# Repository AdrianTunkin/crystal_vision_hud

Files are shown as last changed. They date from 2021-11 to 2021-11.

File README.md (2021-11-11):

# CRYSTAL VISION HUD
### Head-Up Display (HUD) System for safe driving

#### Attention: This repository does not contain diagrams and drawings of projector optics. 
#### Also repository does not contain information regarding mechanical parts, including servos.

Crystal Vision is a portable Head-Up Display (HUD) system that projects an image on the windshield of your car. 
Both the driver and the passengers see it as a semi-transparent image that “levitates” over the hood of the car.

#### Copyright (C) 2015-2018, Crystal Vision Ltd.

https://user-images.githubusercontent.com/49099551/141296656-99a9382b-fc6b-408f-bb68-5c6743e9c2cb.mp4

## VISUAL CHARACTERISTICS

* Resolution: 854 x 480
* Perceived distance: 1.8-2.2 meters (depends on winshield geometry)
* Size: 17"
* Frequency: 60 Hz
* Color coverage:  ~70% sRGB
* Brightness: 1150 cd/m² (only for visible parts)
* Proprietary Remote Canvas technology

## TECHNICAL SPECIFICATIONS

* CPU: Allwinner H6 Quad-Core 64-bit Cortex-A53 @ 1.8GHz
* RAM: LPDDR3 2Gb @ 533Mhz
* ROM: 32Gb TF/MMC
* Power supply: DC 12V, 1.2A (max)
* Interfaces: IEEE 802.11 b/g/n (WiFi), Bluetooth 5.1, USB 2.0, OBDII
* Control OS: Android 9.0 Pie
* Dimensions: 83mm x 52mm x 30mm
* Weight: 115g

## TERMINOLOGY

* Projector - device for displaying projected images in windshield.
* Host phone — the phone on which the manager and client applications are installed.
* Manager - a gateway program through which client applications send graphic messages to the projector.
* Client application - an android application that, using the RemoteCanvas API, draws graphic messages on the projector. 

## DESCRIPTION

The CRYSTAL_HUD_MANAGER module is an android application that is installed on the host phone and acts as a gateway through which applications send messages to the projector.

The CRYSTAL_HUD_MANAGER function as a gateway includes:
* Controlling the concurrent access model of client applications to the projector
* Prioritize access for different applications
* Authorization of client applications.
* Work with three modes: asynchronous messages, synchronous messages, streaming. 

## WEB RESOURCES:

http://crystal-hud.tech Crystal Vision HUD information web site

https://github.com/AdrianTunkin/crystal_vision_hud - GitHub web site hosting the Hardware and Software sources

## LICENSE

### HARDWARE
The Hardware project is released under the Creative Commons Attribution-Share Alike 3.0 United States License.
You may reproduce it for both your own personal use, and for commercial use. 
You will have to provide a link to the original creator of the project http://crystal-hud.tech on any documentation or website.
You may also modify the files, but you must then release them as well under the same terms.
Credit can be attributed through a link to the creator website: http://crystal-hud.tech

### SOFTWARE
The software is released under GPL3.

### DOCUMENTATION
The documentation is released under the Creative Commons Attribution-Share Alike 3.0 United States License.

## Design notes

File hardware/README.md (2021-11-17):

# CRYSTAL VISION HUD
### Head-Up Display (HUD) System for safe driving

Crystal Vision is a portable Head-Up Display (HUD) system that projects an image on the windshield of your car. 
Both the driver and the passengers see it as a semi-transparent image that “levitates” over the hood of the car.

#### Copyright (C) 2015-2018, Crystal Vision Ltd.

Hardware directory contains hardware schematics, design sources, and revision changes designed in KiCad EDA software.



The Crystal Vision HUD electronic board is 6 layer PCB.

#### Technical specifications

* CPU: Allwinner H6 Quad-Core 64-bit Cortex-A53 @ 1.8GHz
* RAM: LPDDR3 2Gb @ 533Mhz
* ROM: 32Gb TF/MMC
* Power supply: DC 12V, 1.2A (max)
* Interfaces: IEEE 802.11 b/g/n (WiFi), Bluetooth 5.1, USB 2.0

Crystal-HUD PCB

### Hardware revision changes log:

#### Hardware revision 1.0

* initial release

#### Hardware revision 1.1

* 1. Adjusted white print of label
* 2. Added bypass near FET2
* 3. Added white print for the UART connector at the bottom of the board
* 4. Fixed white print of R106 and R116
* 5. R29 placed a bit further from C84

#### Hardware revision 2.0

* 1. Changed from eMMC 4GB 1.00mm pitch to eMMC  16GB 0.50mm pitch.
* 2. C212 and C213 were increased to 33pF and to 0402.
* 3. R66 value changed from NA(0R) to NA(22R)
* 4. RM15's package changed from RA1206_(4X0603)_4B8_22R to RA0805_(4X0402)_22R as component optimisation.
* 5. C119 and VR1 changed from PTH to SMT type in the KiCad settings. In reallity, C119 and VR1 did not change. 
* 6. PWRLED1 and CHGLED1 labels corrected in the white print.
* 7. WP_Enable1 jumper added to the SPI_Flash.
* 8. U4 changed from NA(H27UBG8T2BTR-BC(TSOP48)) to NA(MT29F64G08CBABA-WP(TSOP48)), i.e. when populated 8GB NAND instead of 4GB.

#### Hardware revision 2.1

* 1. eMMC KLMAG2GEND-B031(FBGA153)(16G) changed with new eMMC KLMAG1JETD-B041(FBGA153)(16G)

#### Hardware revision 2.2

* 1. Added R62(10k/0402) pull-down to the eMMC's data strobe line;
* 2. RM14, RA0805_(4X0402)_22R replaced by 4 resistors 22R/0402, i.e. R121-R124;
* 3. R73[NA(22R/0402)] was added to enable SPI0 software CS option to the UEXT via PH10, when the SPI_Flash is populated.
* 4. L9 was changed from 2.7nH/L0402 to NA(2.7nH/L0402), and C88 from 24pF to NA(24pF);
* 5. MIPI-DSI1 changed: MIPI-DSI1 connector's pinout completely changed for Raspberry-Pi compatability; added the resistors: R125 to R132;
* 6. In the DRC drill to drill clerance was set to 12mils and all related errors were corrected;
* 7. UEXT1 was changed from NA(HN2x5) to HN2x5;
* 8. All 3Ds were assigned;
* 9. It was added C94(NA/0402) to the eMMC's clock line just in case;
* 10. NAND and related components removed forever;
* 11. In the schematic all "/" signs were exchanged with "\";
* 12. Improvements around the placement of a number of resistors related to the PHY signals to reduce EMI emissions;
* 13. Added U4 EEPROM - AT24C16C-SSHM-T(SOIC-8_150mil) and also C39, 100nF/10V/10% to the UEXT's I2C to avoid conflict with the same EEPROM
* 14. R15[NA(22R/R0402)] added in serial to the eMMC's datastrobe signal to be able to disconnect when no HS400 mode or to add a serial filter to reduce EMI;
* 15. U2 and U3's packages improved;

#### Hardware revision 2.3

* 1. Added antenna ANT2(NA(U.FL-R-SMT-1)), R16(0R) and R17(NA/0R);
* 2. Removed FB1(FB0402/PZ1005U601-R45TF-1) and FB2(FB0402/PZ1005U601-R45TF-1) and placed R18(22R/0402) and R19(22R/0402) resistors instead.;
* 3. Adjusted the lengths of some eMMC wires;
* 4. C93 changed from 24pF to 24pF\50V/5%. C88 and C198 changed from NA/24pF to NA(24pF\50V/5%);
* 5. Changing 5.1 eMMC at 3.3V (up from 1.8V operation) for better reliability, PWR_PC1 jumper has to be set to position 1-2 for 3.3V operation.

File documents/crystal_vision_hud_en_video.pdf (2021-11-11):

# Crystal Vision

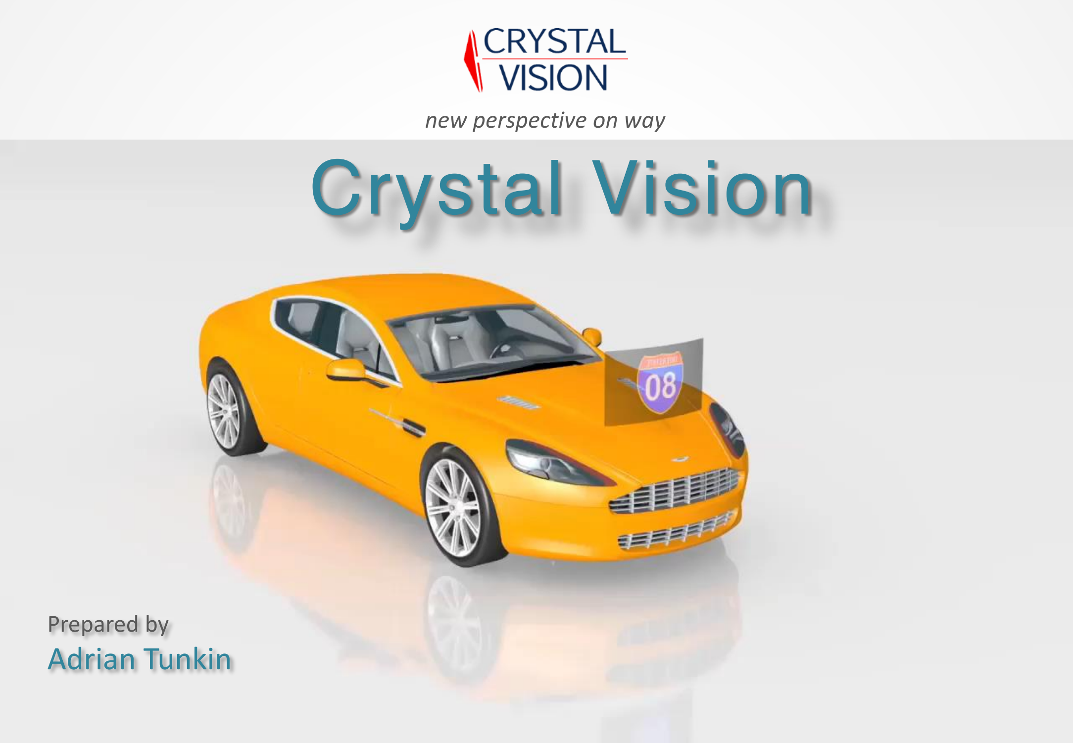
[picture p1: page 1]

new perspective on way

Prepared by

## Adrian Tunkin

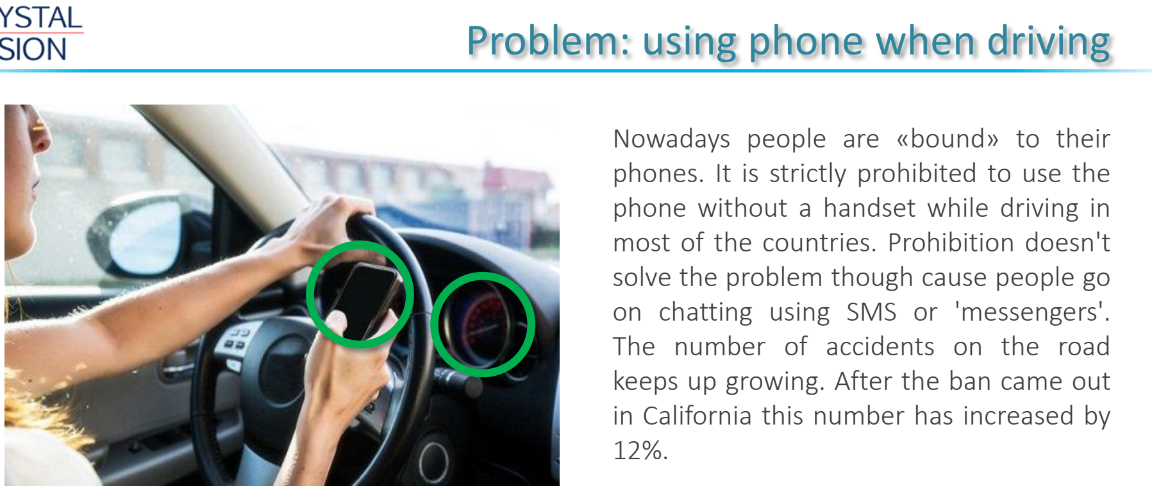
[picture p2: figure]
Problem: using phone when driving; Nowadays people are «bound» to their; on chatting using SMS or 'messengers'. The number of accidents on the road

Looking away from the road for just 2 seconds increases the risk of an accident by 9 to 24-fold

About 78% of people use the smartphone behind the wheel

Only eye refocusing takes 0.3 -0.6 sec which gives extra 50 feet to braking distance

Reflex time increases by 400% while typing SMS or checking email at the wheel

www.crystal-hud.com

phones. It is strictly prohibited to use the phone without a handset while driving in most of the countries. Prohibition doesn't solve the problem though cause people go

keeps up growing. After the ban came out in California this number has increased by

## Frightening consequences

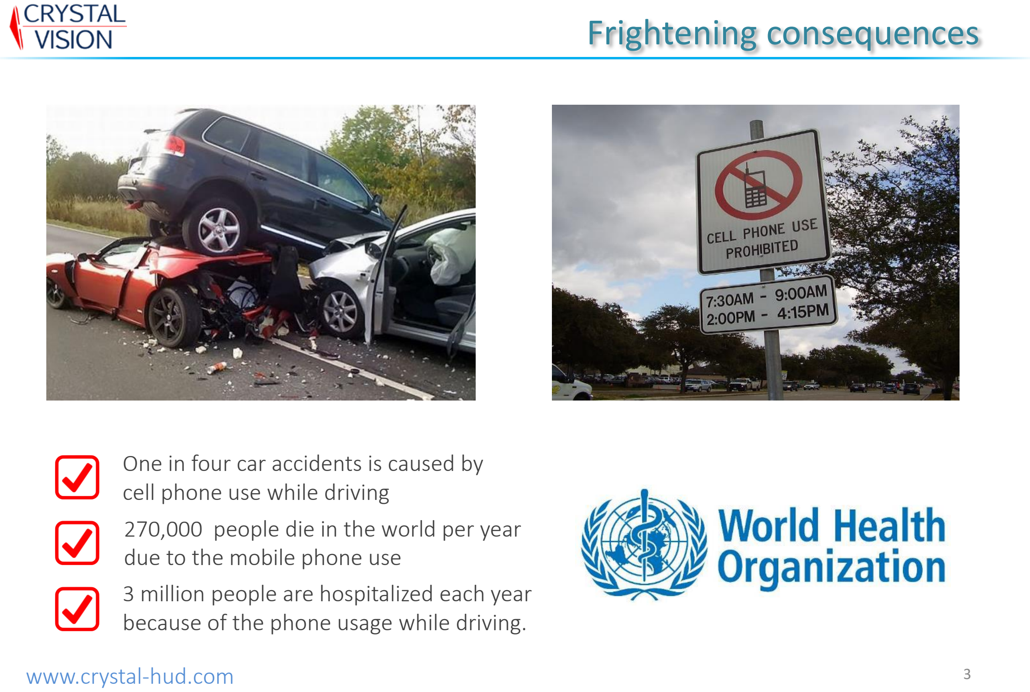
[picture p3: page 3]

270,000 people die in the world per year due to the mobile phone use
3 million people are hospitalized each year because of the phone usage while driving.

One in four car accidents is caused by cell phone use while driving

## Solution: Crystal Vision HUD

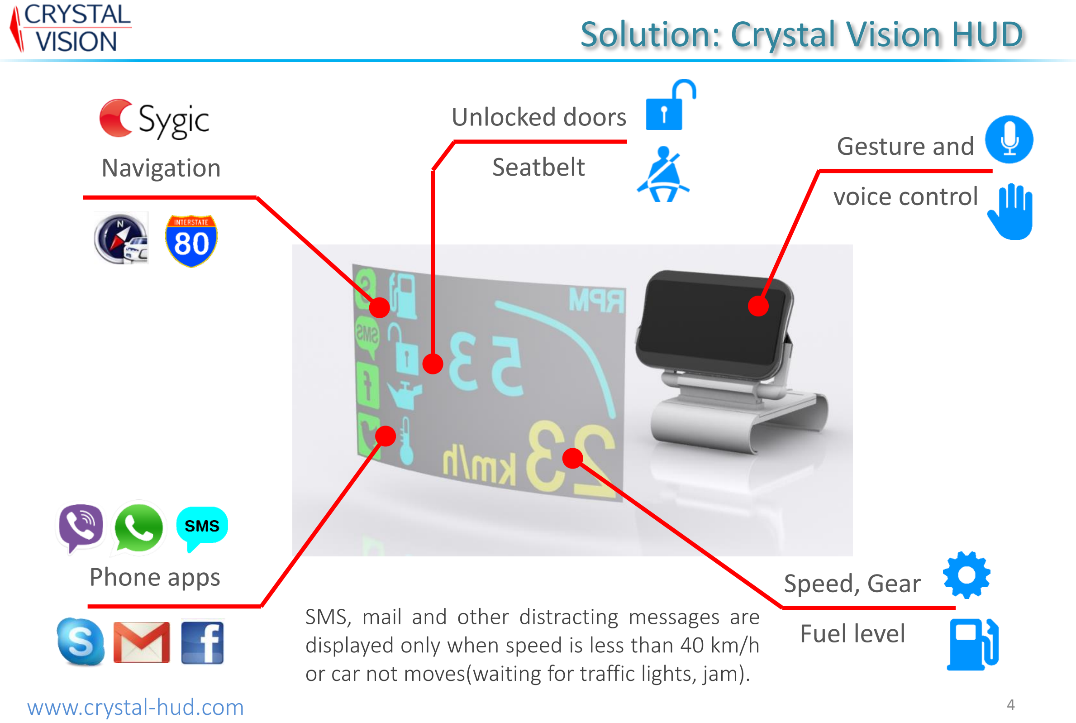
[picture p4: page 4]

Navigation

Speed, Gear

Fuel level

Unlocked doors

Seatbelt

Phone apps

Gesture and

voice control

SMS, mail and other distracting messages are displayed only when speed is less than 40 km/h or car not moves(waiting for traffic lights, jam).

Crystal Vision is a portable HUD system, that projects image on a windshield of your car. Driver and passengers see it as a semitransparent image that “levitates” above the car bumper and is not seen from outside. Projector is controlled via an app installed on the smartphone. The application aggregates data from the cloud services and smartphone applications, onboard computer and sends it in a special format to the projector. See the video. (https://youtu.be/zcKgM1mWc0Q)

Application
manager

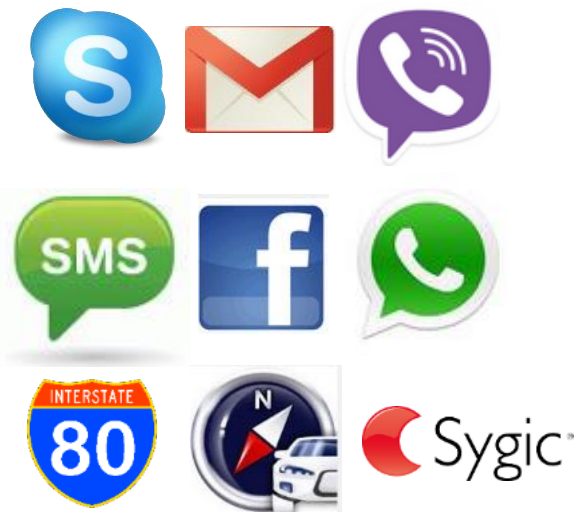
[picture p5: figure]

3d party applications
(info providers)

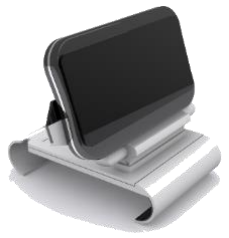
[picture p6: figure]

API

Crystal Vision HUD

## Created image examples

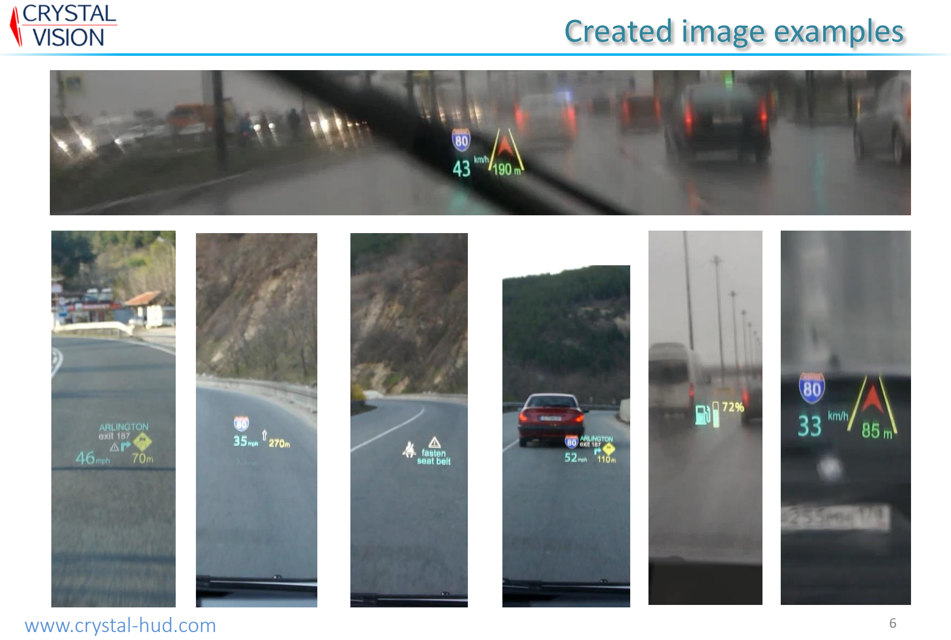
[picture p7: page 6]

www.crystal | 6 -hud.com

Currently in the World there are only a few competitors that offer embedded HUD systems. They are early bird companies that only offer pre-ordering their products.

Continental provides factory installed solutions for luxury cars segment. Audi, BMW, Mercedes: all those brands are equipped with Continental HUD systems if option is chosen when ordering car.

Crystal creates pristine image that is of the same quality as created by HUD systems in luxury cars.
Crystal HUD is portable and can be installed into any car.

Crystal vs. factory

Crystal HUD cost is 5 to 10 times less than factory HUD systems and is the same for embedded HUD systems.

Crystal HUD allows a variety of information to be displayed, which is chosen by a user. In contrast, factory HUDs display info is determined by manufacturer, typically, navigation only.

Crystal vs. portable

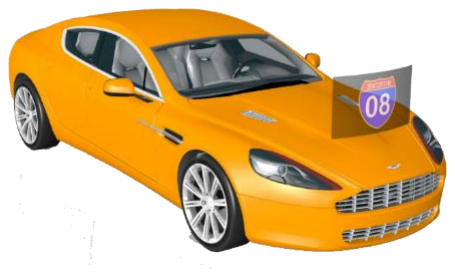
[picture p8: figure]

Since we have solved image-doubling problem, Crystal HUD doesn’t require neither reflective plates nor films, which are used in other competitive products. Image is created right on a windshield.

Image created by Crystal HUD is remote, it “levitates” over the car hood and appears to be 1,7 – 2,3 m up the driver’s eyes. This allows not to refocus the sight as the image is already in the field of vision. Driver doesn’t get distracted from the road. According to the latest research, that is crucial point for driving safety and differs Crystal HUD from other pseudo “HUD” systems.

Crystal HUD can be tuned up to show image below, on or above horizon line. Image is well seen in any conditions: day and night, sun and rain, snow and fog. Image is also seen by passengers.

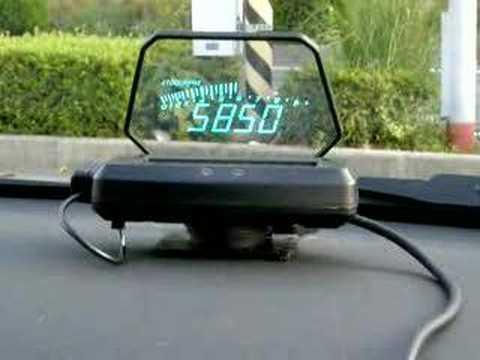
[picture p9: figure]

Competitive
portable “HUD”

## Factory HUD vs. Crystal Vision HUD

Factory HUD | Crystal Vision

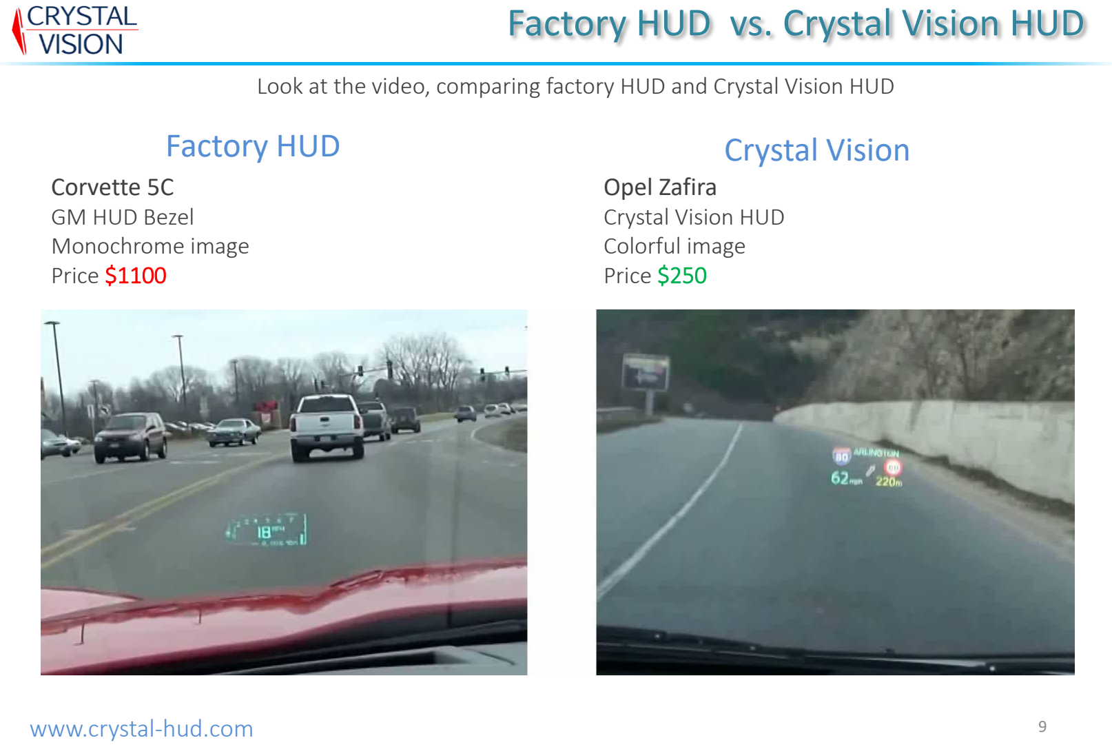
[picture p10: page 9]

Corvette 5C
GM HUD Bezel
Monochrome image
Price $1100

Opel Zafira
Crystal Vision HUD
Colorful image
Price $250

Look at the video, comparing factory HUD and Crystal Vision HUD

50%

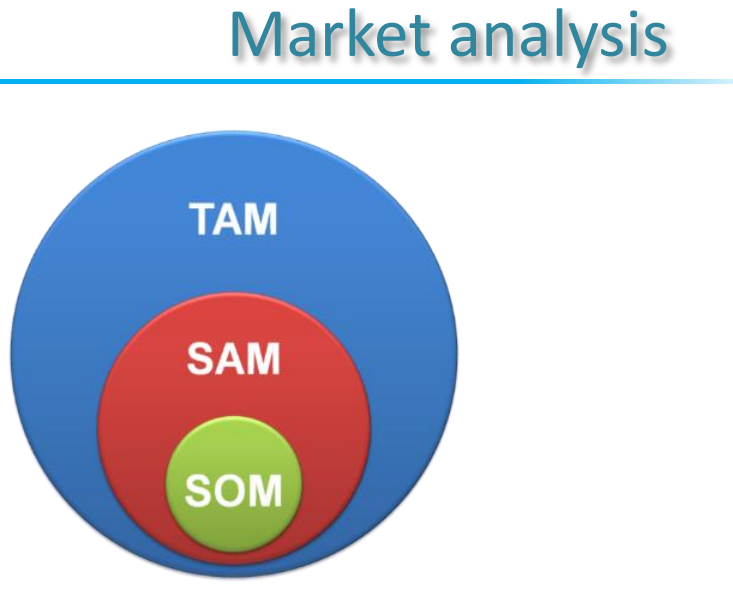
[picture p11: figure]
Market analysis

Total Available Market (TAM) = 1150 m. – all cars in the world driven every day

Serviceable Available Market (SAM) = TAM x 87% - passenger cars
x 90% - cars that support technology х 70% - use smartphone while driving = 630 million

Serviceable Obtainable Market (SOM) = Russia 40 m. passenger cars + China 117 m. passenger cars +
USA 220 m. passenger cars +
Europe 250 m. passenger cars
= 627 х 90% х 70% = 395 million | 1150

630

395

0 | 500 | 1000 | 1500

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
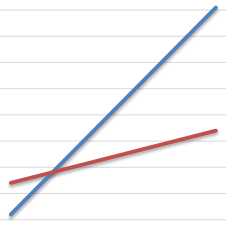
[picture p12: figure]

2012 | 2020

Growth of number of cars with HUD option, millions

0

1000

2000

3000

4000

5000

6000

7000

8000

9000

2014 | 2017 | 2020
Fast growing market,
millions of USD

According to a new market research report, the global head-up display market is estimated to reach USD 9.02 Billion by 2020, at a CAGR of 26.23% between 2015 and 2020. The market for the automotive application is expected to grow at a CAGR of 29.28% during the forecast period. This growth is driven by the increasing demand for mid-segment and sport cars globally. (source: MarketsandMarkets) (http://www.marketsandmarkets.com/Market-Reports/head-up-display-hud-market-684.html)

## How do we make money

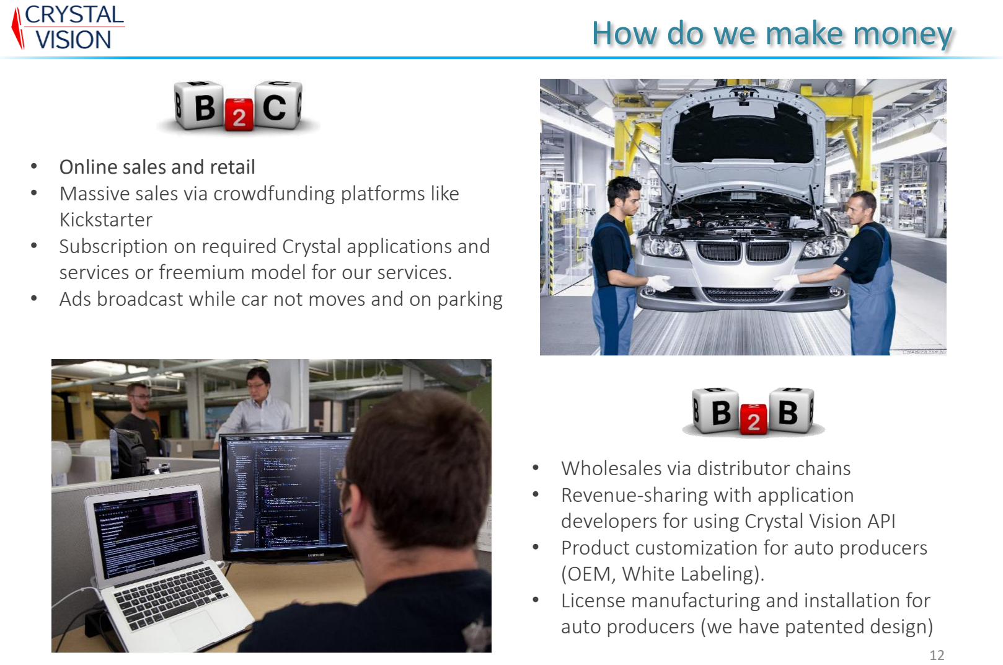
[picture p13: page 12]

- Online sales and retail
- Massive sales via crowdfunding platforms like Kickstarter
- Subscription on required Crystal applications and services or freemium model for our services.
- Ads broadcast while car not moves and on parking
- Wholesales via distributor chains
- Revenue-sharing with application developers for using Crystal Vision API
- Product customization for auto producers (OEM, White Labeling).
- License manufacturing and installation for auto producers (we have patented design)

50%

Who is interested in the product:
- Our audience - car owners.
- Car producers.

How to promote the product:

- Actually, distributors from all over the world already find us and offer partnership, distribution and promotion in their countries.
- Sales web-page http://crystal-hud.com.
- Attractive car stickers and shields in the set with the device.
- The device advertises itself attracting drivers and passengers’ attention with its outer look (from mouth to mouth marketing or “the rumour mill”).
- Equipment of foreign car rent services chains (Top Rent Car, Herz, etc.) or test-drive cars will let many people get to know the product.
- Commercials on web-sites devoted to cars (auto.ru, autoblog.com, auto.de).
- Gadgets overview web-sites (digitaltrends.com, cnet.com, engadget.com).
- Car magazines, brochures, TV-shows and video casts (“Top gear”, “Big test-drive”), social network communities, messages in blogs.

50%

- Factory HUD system | $1100 - $3000
- Pioneer HUD system NavGate | $930
- NAVDY pre-order | $299 ($499)
- Crystal Vision HUD | $250
0 | 1000 | 2000 | 3000 | 4000

Crystal Vision

Navdy

Embedded HUDs

Pioneer NavGate

Factory HUDs

max min

50%

Crystal Vision projector
1. Patent pending (Russian) 100%
2. Patent pending (international) 35%
3. Trademark registration | 70%
4. Minimum Functional Prototype (MFP) 100%
5. Complete Functional prototype (CFP) 92% optic elements 100%
electronics (PCB) 85%
enclosure and mount 90%
6. Design-For-Manufacture(DFM) 59%
optic elements | 100%
prototype elements | 90%
molds | 40%
certification 5%

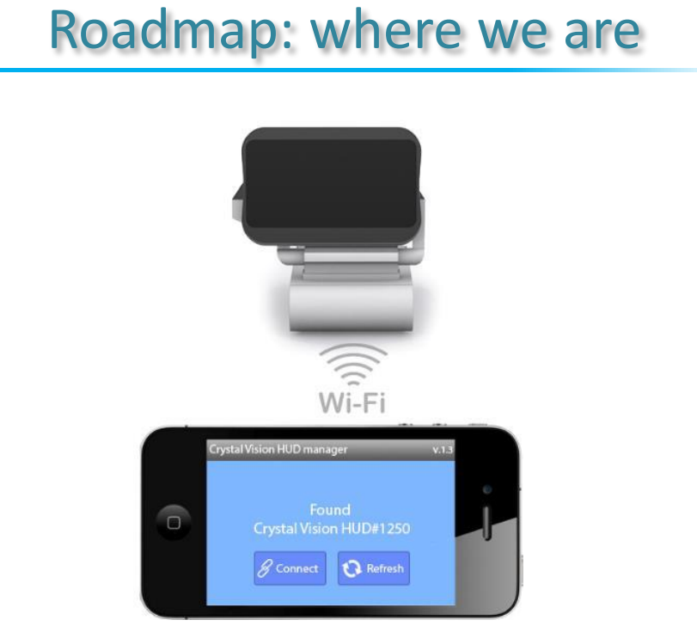
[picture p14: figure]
Roadmap: where we are

7. Suppliers of electronic components, elements and materials 100 %
8. Potential resources for manufacture, assembly, packaging 100 %
9. Packaging 0%
10. First factory run (FFR) 0%
11. Retail 0%

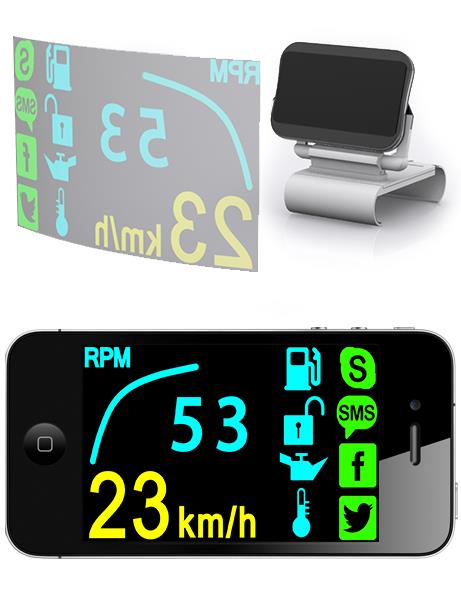
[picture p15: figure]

50%

Software development
1. Crystal Vision Application Manager
for Android 85%
for iOS 10%
2. Remote animations engine “Remote Canvas” for Android 95%
for iOS 10%

Common
1. Kickstarter campaign 70%
2. Distribution channels
USA | 40%
China | 0%
Finland 50%
Germany 10%
Thailand 70%
Bulgaria 70%
3. Marketing 2%

50%

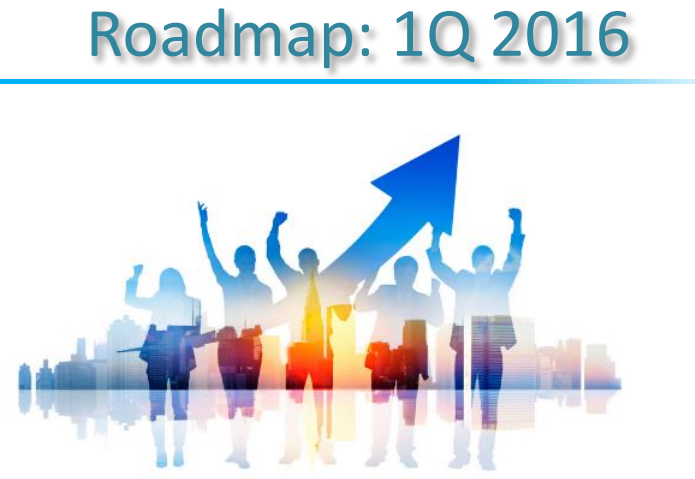
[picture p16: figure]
Roadmap: 1Q 2016

Estimated progress status at the end of 2015 - 1Q 2016

Crystal Vision projector
1. Patent pending (Russian) 100%
2. Patent pending (international) 80%
3. Trademark registration | 100%
4. Minimum Functional Prototype (MFP) 100%
5. Complete Functional prototype (CFP) 100%
6. Design-For-Manufacture (DFM) 80 - 100%
7. Suppliers of electronic components, elements and materials 100%
8. Potential resources for manufacture, assembly, packaging 100%
9. Packaging 100%
10. First factory run (FFR) 60 - 100%
11. Retail 60 - 90%

Software development
1. Crystal Vision application manager 100%
2. Remote animations engine “Remote Canvas” 100%

Common
1. Kickstarter campaign 100%
2. Distribution channels 90%
3. Marketing | 60-100%

50%

- Fixed production costs $65K
- Industrial design finalization $21K hardware finalization $11K software finalization $10K
- Assembly $32K
- Packaging $6K
- Engineering Validation Test(EVT) $2K
- Certification | $2K
- Design Verification Test(DVT) | $2K
- Delivery $12 per unit
- Variable costs $16 per unit
- Business trips 6 months | S10K
- Outsource and custom works | $5K
- International Patent finalization $20K
- First 5K batch (KickStarter campaign, distributor channels)
- Incomes - $1,250,000(5K x $250)
- Fixed costs $65 per unit
- Profit per unit $157
($250 - $65 -$12 - $16)
- Profit for batch $785,000
(5K x $157)
- Second and another batches profit per unit $170
- Distribution channels and Wholesale (FOB price $180) profit per unit $95 ($180 - $65 - $4 Delivery - $16)

## Profit 2016

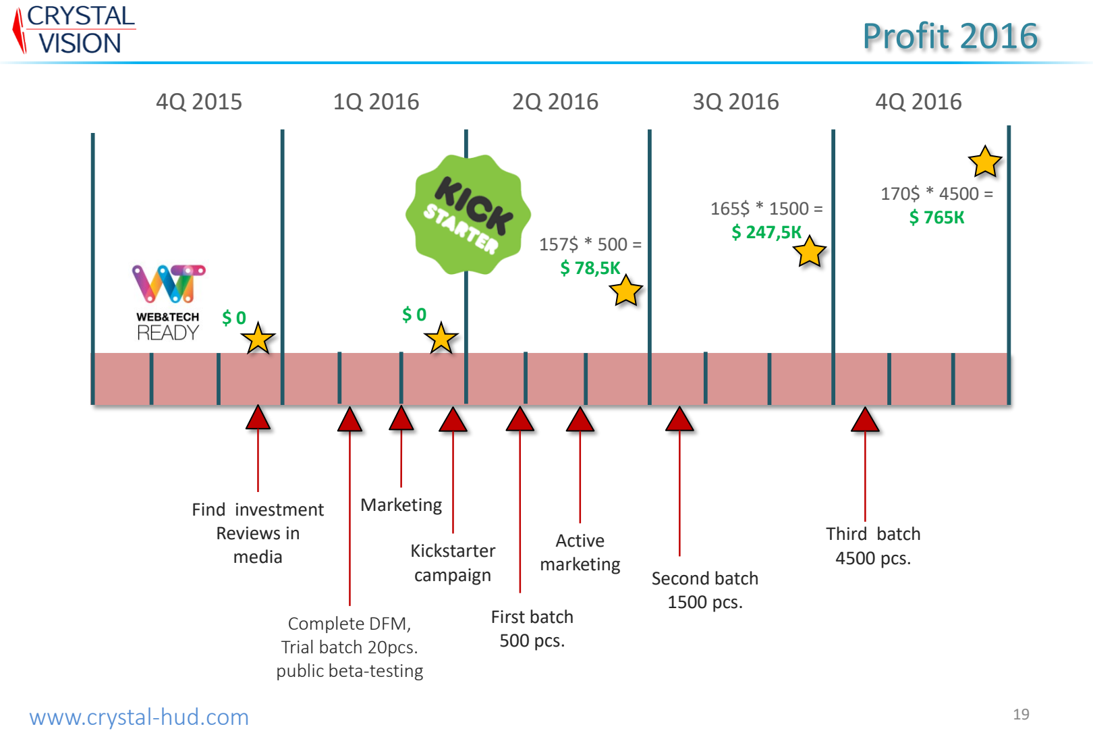
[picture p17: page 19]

4Q 2015 | 1Q 2016 | 2Q 2016 | 3Q 2016

Complete DFM,
Trial batch 20pcs.
public beta-testing

Kickstarter
campaign

First batch
500 pcs.

Active
marketing

157$ * 500 =
$ 78,5K
$ 0 | $ 0

165$ * 1500 =
$ 247,5К

Second batch
1500 pcs.

170$ * 4500 =
$ 765К

4Q 2016

Find investment
Reviews in
media

Third batch
4500 pcs.

Marketing

# | Risk | Description | Threat | Remediation

1 | Economic | Foreign exchange volatility influences the purchasing ability in different countries and price setting of the product. | High | Price division according to the country. We made a survey in different countries what price the customers are ready to pay for it.
2 | Production | Nonfulfillment of baseline work, failure to meet the deadline. | Moderate | We already have partners with two-time stock volumes. We are setting up new contacts with partners in different countries for product sales.
3 | Legal | Prohibition on Crystal HUD implemented systems usage in certain countries. | Low | Crystal HUD doesn’t use any cover-up on windshield, no reflection glass which can disturb the driver. Switch to other markets.
4 | Low demand | Low demand | Moderate, Low | Percent order in relation to the overall number of clicks on the site, 19%. Presentation, survey in the US, 65%. Presentation, survey in Germany, 71%.
5 | Strategic | Patents infringement, manufacturing of products functionally close to it. | High | Intellectual property rights, protection of interests in court.
6 | 50% Compliance | Ban of Application Manager on AppStore and Google Play Market. | Low | Compliance with the rules and guidelines for application development.
7 | Legal, Regulatory | Ecological norms and rules violation, problems of standardizing and licenses. | Low | We don’t use any toxic, poisoning or contaminating substances. We use mercury-free and lead-free components and soldering, RoHS compliant.

Until recently we didn’t participate in any events,

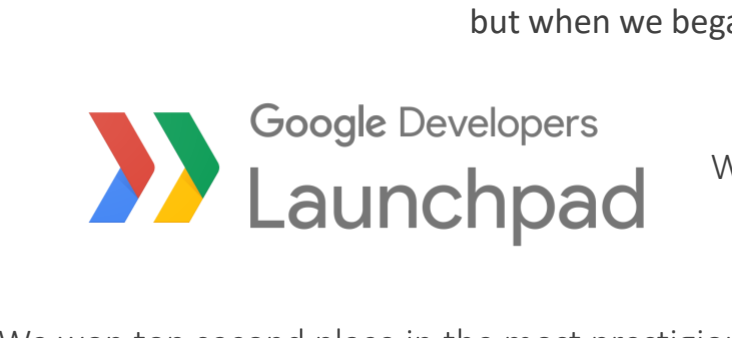
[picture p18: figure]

but when we began we won several prizes:

We are the member of Google Launchpad program.

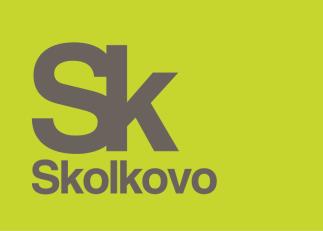
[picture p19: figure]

We’ve patented technology in RosPatent. And now still pending for technology enhancement patent.

We won top second place in the most prestigious Russian competition. There were 712 competing projects from 14 countries.

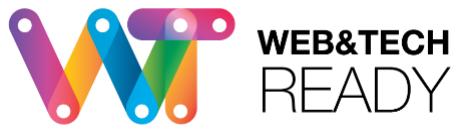
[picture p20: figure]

We won high technology acceleration program in Skolkovo Innovation Center.

## Testimonials

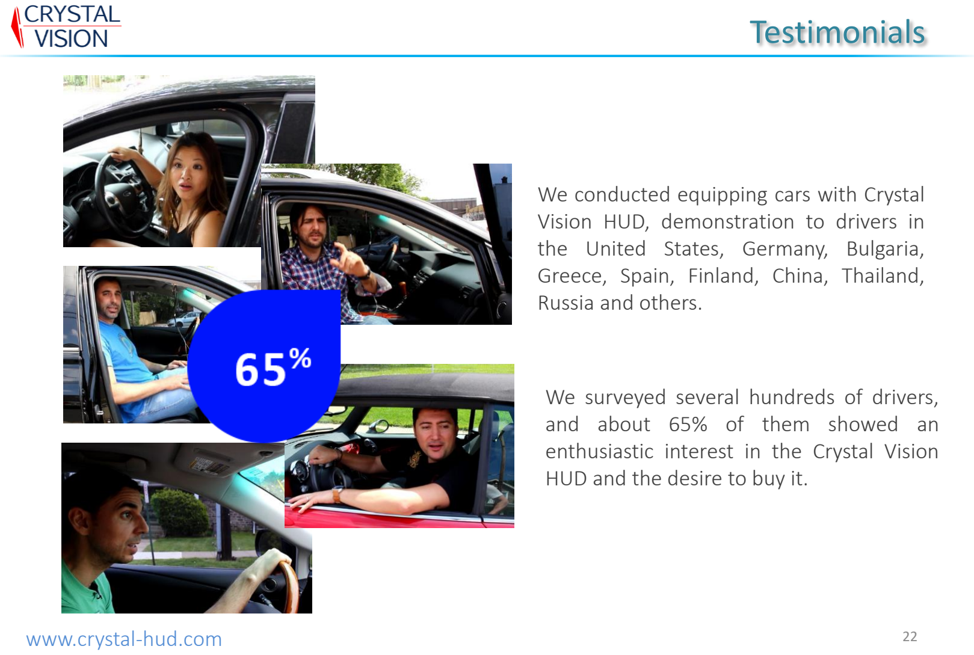
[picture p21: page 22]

We conducted equipping cars with Crystal Vision HUD, demonstration to drivers in the United States, Germany, Bulgaria, Greece, Spain, Finland, China, Thailand, Russia and others.

We surveyed several hundreds of drivers, and about 65% of them showed an enthusiastic interest in the Crystal Vision HUD and the desire to buy it.

We spent about 3 years for technology R&D, and now have finished it. Product is 75-80% ready and we will start production soon.
We need money, for:
- Finalizing industrial prototype
- Preparation for mass production
- First batch production
- Marketing
- Preparing for Kickstarter campaign (commercial and reviews in media)
- Outsourced works (design, software)
- Patenting, certification and other legal affairs

We have of about 220 preorders now. Genuine interest to our product, distribution offers, crowdfunding success of related projects (Navdy, (http://www.entrepreneur.com/article/245093) HUDWAY, (https://www.kickstarter.com/projects/361842686/hudway-glass-keeps-your-eyes-on-the-road-while-dri) Expolride) (https://www.indiegogo.com/projects/exploride-turn-your-car-into-a-smart-car#/) and our competitive advantages let us assume great success.

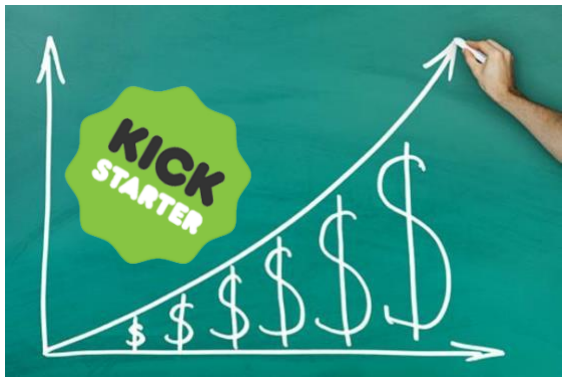
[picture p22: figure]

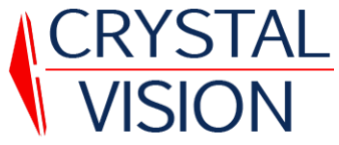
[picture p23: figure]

Let’s turn every car into a safe spaceship, and make business together

Any questions :
phone: +7(903)095-01-47
еmail: adrian@crystal-hud.com web: http://crystal-hud.com

Analytics, statistics, development prospects

- http://www.marketsandmarkets.com/Market-Reports/head-up-display-hud-market-684.html (http://www.marketsandmarkets.com/Market-Reports/head-up-display-hud-market-684.html)
- http://press.ihs.com/press-release/design-supply-chain/automotive-head-display-market-goes-high-gear (http://auto.cnews.ru/news/byid/534108)
- http://www.acea.be
- https://en.wikipedia.org/wiki/Motor_vehicle
- http://chartsbin.com/view/1114
- https://en.wikipedia.org/wiki/List_of_countries_by_vehicles_per_capita
- http://www.who.int/en/ (http://auto.cnews.ru/news/byid/534108)

HUD products
- http://www.youtube.com/watch?v=-8SP1OSIpaM (http://auto.cnews.ru/news/byid/534108)
- http://www.edmunds.com/mazda/mazda3/2014/long-term-road-test/2014-mazda-mazda3-heads-up-display.html (http://www.edmunds.com/mazda/mazda3/2014/long-term-road-test/2014-mazda-mazda3-heads-up-display.html)
- http://www.pioneer.eu/eur/products/archive/SPX-HUD01/page.html
- http://www.youtube.com/watch?v=Qg8dq9FlX78

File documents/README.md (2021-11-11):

# CRYSTAL VISION HUD
### Head-Up Display (HUD) System for safe driving

Crystal Vision is a portable Head-Up Display (HUD) system that projects an image on the windshield of your car. 
Both the driver and the passengers see it as a semi-transparent image that “levitates” over the hood of the car.

#### Copyright (C) 2015-2018, Crystal Vision Ltd.

Documents directory contains:

* English presentation
* Visio file with hierarchy of application classes
* Files, concerned the patent

The patent itself is written in Russian (not translated).

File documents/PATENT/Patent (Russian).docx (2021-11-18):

МПК G02B 27/01

Название изобретения

Метод формирования мнимого изображения для системы проецирования информации на лобовое стекло HUD(Head Up Display).

Область техники, к которой относится изобретение

Изобретение относится к системам проецирования информации на лобовое стекло, в частности на лобовое стекло автомобиля. Эта система позволяет создавать мнимое изображение, которое висит над капотом или бампером автомобиля, и позволяет водителю управлять транспортным средством, не отвлекаясь от дороги. Показания скорости, оборотов, навигационные данные или другие данные сами попадают в поле зрения и не требуют перефокусировки зрения для чтения информации. Такие системы называются системами HUD(от англ. Head Up Display). Сейчас такие системы так же называются расширителями дополненной реальности – от англ. AR Devices(Augmented Reality Devices).

Далее в этом документе системы проецирования информации на лобовое стекло будут называться системами HUD.

Уровень техники

Известны штатные (заводские) системы HUD и встраиваемые системы HUD.

Штатные системы HUD - это сложные оптические системы, которые расчитываются под конкретную марку автомобиля и предполагают заводскую установку и настройку при сборке автомобиля. Как и любая оптическая система, система HUD занимает некоторый объем, поэтому в пространстве передней панели должно быть место для установки системы HUD. Так же в передней панели должно быть окно для прохождения светового потока от изображения. Кроме того ключевую роль в таких системах играет лобовое стекло, которое должно создавать четкое изображение без раздвоения. Лобовое стекло является самым дорогостоящим оптическим элементом систем HUD.

Установка штатной системы HUD невозможна после выпуска и продажи автомобиля.

Большинство патентов на системы HUD - это патенты на штатные (заводские) системы, устанавливаемые при сборке автомобиля.

Недостатками штатных систем HUD являются:

1. Очень высокая стоимость систем, технологическая сложность изготовления лобовых стекол.
2. Система должна быть запрошена при заказе автомобиля. Дальнейшая установка системы HUD невозможна или очень дорогостоящая.
3. Изображение видно только водителю и не видно пассажирам, а есть необходимость выводить не только автомобильную информацию для водителя, но и общеполезную информацию для всех пассажиров.

Существуют также встраиваемые системы HUD. Эти системы разработаны для установки в автомобили, у которых нет штатной системы HUD.

Примеры встраиваемых систем HUD:

- встраиваемая система HUD производства Garmin [1];
- встраиваемая система HUD производства Defi [2];

Эти системы представляют собой законченные устройства в корпусе. Устройство устанавливается на переднюю панель автомобиля и фиксируется двухсторонней липкой лентой. В корпусе есть микропроцессор и зашита программа, которые обрабатывают данные автомобиля, или мобильного телефона поступающие по интерфейсу Bluetooth.

Микропроцессор создает изображение на индикационном элементе устройства. Это изображение отражается от лобового стекла автомобиля, или от специального тонкого поликарбонатного стекла, крепящегося к самому устройству.

Недостатками этих встраиваемых систем HUD являются:

1. Для корректной работы этих систем требуется специальное отражающее стекло, которое идет в комплекте с устройством и крепится к самому устройству, либо специальная отражающая или затемняющая пленка, которая клеится к лобовому стеклу. Посторонние предметы на лобовом стекле (пленка) или отражающее стекло крайне нежелательны, так как отвлекают водителя от вождения и загораживают вид водителю. К тому же они нарушают эргономичность всей системы HUD.
2. Недостатком этих систем является то, что они создают мнимое изображение на уровне лобового стекла, а не над бампером как в заводских системах HUD.
3. Недостатком является то, изображение видно только водителю и не видно пассажирам, а есть необходимость выводить не только автомобильную информацию для водителя, но и общеполезную информацию для всех пассажиров.
4. Недостатком является то, что у приведенных выше встраиваемых систем HUD изображение не графическое. Отображаются только предопределенные символы и ограниченный набор фигур.

Известна также встраиваемая система HUD производства фирмы Pioneer [3].

Система производится в корпусе, который крепится ремешками к солнцезащитному козырьку автомобиля. В корпусе есть микропроцессор и зашита программа, которые обрабатывают данные бортового компьютера автомобиля, или данные с мобильного телефона, поступающие по интерфейсу Bluetooth. Микропроцессор и программное обеспечение формируют изображение на дисплее устройства. Дисплей находится со стороны головы водителя и формирует световой поток изображения в сторону лобового стекла. Изображение, формируемое дисплеем, отражается от изогнутой поликарбонатной пластинки на стороне устройства, находящейся со стороны лобового стекла. Водителем это изображение воспринимается как удаленное увеличенное изображение.

Недостатками данной системы являются:

1. Информация проецируется не на лобовое стекло, а на стеклянную панель перед глазами водителя. Это вызывает неудобство водителя.
2. Недостатком является то, что данная система также создает недостаточно удаленное мнимое изображение.
3. Недостатком является то, изображение видно только водителю и не видно пассажирам, а есть необходимость выводить не только автомобильную информацию для водителя, но и общеполезную информацию для всех пассажиров.

Наиболее близким аналогом данного изобретения является система HUD описанная в патентной заявке США US7990620 B2 от 02.08.2011 см. Приложение 1, фиг.15. Эта система использует источник излучения (лазерный луч) 102, который формирует изображение на рассеивающем элементе 104 (белый лист, экран и т.д.). Реальное изображение, формируемое рассеивающим элементом 104 установленным на передней панели 108, отражается от лобового стекла 106 и попадает в глаз водителя.

Главным недостатком данной системы HUD является то, что независимо от расположения источника света (лазерного луча)102, реальное изображение формируется не на источнике излучения, а на рассеивающем элементе 104, который располагается на передней панели автомобиля 108. Это означает, что удаленность Dv мнимого изображения 114 равна расстоянию от рассеивающего элемента 104, лежащего на передней панели 108, до места отражения на лобовом стекле 106, то есть Dv = Dp. Данное расстояние в среднем равно 170 миллиметрам.

Кроме того, поскольку удаленность мнимого изображения мала, изображение сильно двоится. Поэтому использование этой системы возможно только со специальным лобовым стеклом (аналогичным штатным системам HUD) или с использованием дополнительных отражающих стекол или отражающих пленок на лобовом стекле (аналогичным встраиваемым системам HUD от Garmin или Defi).

Раскрытие изобретения

Задача, на решение которой направлено заявляемое изобретение, состоит в том, чтобы создать систему HUD, в значительной мере свободную от перечисленных выше недостатков штатных и встраиваемых систем HUD, а также аналогов. Так же, поскольку информация может быть не только сугубо автомобильной, предназначенной для водителя, но и общеполезной для всех пассажиров, при разработке сделан акцент на возможность формирования изображения, видимого всем пассажирам. Заявляемая встраиваемая система HUD включает в себя:

- микропроцессорное устройство 3, получающее информацию из автомобиля или мобильного телефона, обрабатывающее ее и отображающее на дисплее 12;

- универсальное крепление устройства 3а, позволяющее крепить устройство 3 к солнцезащитному козырьку 1 или центральному зеркалу заднего вида 2. Крепление позволяет настраивать угол устройства так, чтобы световой поток дисплея 12 был направлен на отражающий элемент 4;

- один или несколько отражающих элементов 4, представляющих собой оптическое или промышленное зеркало. Несколько отражающих элементов используются, когда необходимо формировать изображения для нескольких пассажиров. По одному отражающему элементу на каждого пассажира;

Техническим результатом изобретения является реализация усовершенствованного метода создания мнимого изображения встраиваемой системы HUD. Предложенный метод построения изображения не использует сложную оптику: ни линзы, ни вогнутые, ни выпуклые зеркала, ни дорогостоящие лобовое стекло или другие элементы.

Основными достоинствами данного метода являются:

- Метод позволяет встраивать систему HUD в любой автомобиль. И в тот, в котором есть штатная система HUD и в тот, в котором нет штатной системы HUD.
- Метод позволяет создавать мнимое изображение, удаленность которого сравнима с удаленностью изображения штатных систем HUD, а иногда ее и превосходит.
- Метод позволяет создавать мнимое изображение, удаленность которого превосходит удаленность всех существующих (описанных выше) встраиваемых систем HUD.
- Метод формирует мнимое изображение, четкость которого сравнима со штатными системами HUD
- В отличие от других встраиваемых систем HUD, метод позволяет отказаться от использования специальных отражающих пленок и других элементов.
- Метод позволяет создавать изображения, которые видны не только водителю, но и пассажирам.

Все это достигается за счет особого расположения источника реального изображения, а так же метода формирования графического изображения.

Источником изображения может быть светодиодная матрица, дисплей или любой другой источник реального изображения. Источник реального изображения крепится на центральное (внутреннее) зеркало заднего вида, находящееся на лобовом стекле, с обратной его стороны. Так же возможно крепление за центральное зеркало заднего вида на лобовое стекло. Вторым, более предпочтительным вариантом является крепление источника реального изображения к солнцезащитным козырькам автомобиля.

Описание чертежей

На фиг.1 представлен способ крепления источника реального изображения на солнцезащитный козырек, ход луча от источника, а также формирование мнимого изображения.

На фиг.2 представлен способ крепления источника реального изображения на центральное зеркало заднего вида, ход луча от источника, а также формирование мнимого изображения.

На фиг.3 изображен путь распространения света в толще лобового стекла в общем случае

На фиг.4 изображен путь распространения света в толще лобового стекла в случае, когда расстояние от реального изображения до лобового стекла меньше, чем расстояние от лобового стекла до глаза.

На фиг.5 изображен путь распространения света в толще лобового стекла в случае, когда расстояние от реального изображения до лобового стекла больше, чем расстояние от лобового стекла до глаза.

На фиг.6 представлены сравнительные графики процентной доли отражения горизонтально-поляризованного света(s-polarization) и вертикально-поляризованного света (p-polarization) в зависимости от угла падения луча.

На фиг.7 показан эффект полной горизонтальной поляризации (s-polarization) отраженного луча, при его падении на поверхность лобового стекла под углом Брюстера.

На фиг.8 изображено в профиль устройство 3. Также на рисунке в профиль показан дисплей 12 с горизонтально-поляризующей пленкой, или пленкой, вращающей плоскость поляризации(retarder film), а также формируемые горизонтально-поляризованные лучи света 13.

На фиг.9 представлена конструкция отражающего элемента с горизонтально поляризованной пленкой.

На фиг.10 представлена возможная конструкция изготовления передней панели со встроенным отражающим элементом для системы HUD при промышленном встраивании системы автомобили.

На фиг.11 представлена возможная конструкция изготовления передней панели со встроенным отражающим элементом для системы HUD и необходимыми плоскостями вращения зеркала при промышленном встраивании системы в автомобили.

На фиг.12 показано раздвоение обычного символа со скруглениями.

На фиг.13 показан пример цифр с прямоугольными элементами.

На фиг.14 представлен пример раздвоения цифр с прямоугольными элементами.

На фиг.15 (в Приложении 1) представлен рисунок, взятый из патента US7990620 B2 от 02.08.2011. На рисунке представлен принцип формирования мнимого изображения, заявленного в патентной заявке США US7990620 B2 от 02.08.2011.

Осуществление изобретения

В системе HUD используются устройство 3, заключенное в небольшой корпус, сравнимый по размерам с современными небольшими мобильными телефонами. Устройство 3 при помощи подвижного крепления 3а, позволяющего менять угол устройства 3, крепится к солнцезащитному козырьку 1 или на центральное зеркало заднего вида 2. Внутри корпуса устройства 3 установлена электронная плата с микропроцессором и зашита программа. Устройство 3 подключается к автомобилю и/или телефону через интерфейс Bluetooth и запрашивает данные с автомобиля и телефона. Микропроцессор и программа обрабатывают данные, и выводят их на индикационный элемент, который представляет собой дисплей. Дисплей формирует реальное перевернутое изображение. Устройство 3 устанавливается так, чтобы световой поток изображения от дисплея был направлен на отражающий элемент 4 (см. фиг.1 и фиг.2) . Отражающий элемент 4, в качестве которого может выступать оптическое или промышленное тонкое зеркало, отражает изображение, формируемое устройством 3, на область лобового стекла 5.

Далее световой поток изображения снова отражается от лобового стекла в области 5 и попадает в глаз водителя 7.

Формула изобретения

В заявленном методе формирования мнимого изображения для системы HUD, расстояния L1 и L2 (см. фиг.1 и фиг.2) складываются, и удаленность S мнимого изображения 6 равна сумме этих расстояний, т.е. S = L1 + L2.

Оценка степени раздвоения мнимого изображения в заявленном методе формирования мнимого изображения и сравнение его с другими системами:

1. Анализ расстояния S для разных марок автомобилей показывает, что среднее значение S для случая крепления источника изображения на солнцезащитный козырек 1 (см. фиг.1) составляет 1220 мм. То есть S = 1220 мм.
2. Анализ расстояния от области отражения лобового стекла 5 до глаза водителя 7 для разных марок автомобилей в среднем составляет 720 мм.

То есть считаем, что C1B = 720 мм.

3. На фиг.3 изображен общий случай распространения луча в толще лобового стекла 16. Из фиг.3 видно: поскольку из геометрической оптики известно, что угол падения равен углу отражения, следовательно, ∠ CBF = η = ∠ C1BF1 = η1.

Аналогично угол ∠ ADE = β = ∠ A1DE1 = β1, из этого следует, что α = α1.

Из равенства углов α и α1 следует равенство прилежащих к ним углов θ и θ1.

Углы δ = 180 – η – θ, δ1 = 180 – η1 – β1 также равны, то есть δ = δ1.

4. Итак, у треугольников ∆CBA и ∆C1BA1 соответственно равны углы:

θ = θ1, η = η1, δ = δ1. Это означает подобие треугольников ∆CBA и ∆C1BA1, то есть ∆CBA ~ ∆C1BA1.

5. Расчет величины AA1: у современных лобовых стекол средняя толщина 5 мм, индекс преломления n = 1.51. Угол падения луча с отражающего элемента 4 на лобовое стекло в области 5 приблизительно равняется ∠(90-η)= 49° . Применяя закон Снеллиуса, получаем:

n=1.51=(sin⁡(90-η))/(sin⁡(90-β))

то есть sin(90-β)= 0.5, а угол ∠(90-η)=30° .

Отсюда получаем AA1 =2*tan(30°)*5мм=5.77 мм

6. Из подобия треугольников ∆CBA и ∆C1BA1 следует равенство отношения их сторон, то есть:

(C1B)/(CB)=(A1B)/(AB)

7. Рассчитаем A1B для системы HUD, предложенной в заявляемом изобретении:

A1B = (C1B * A1A)/(C1B+CB)= (720 * 5.77)/(720+1220) = 2.1 мм

Применяя закон синусов к треугольнику ∆C1BA1, получаем:

sin(δ1) = (A1B * sin⁡(η1))/(C1B)=(2,1 * sin⁡(41°))/720 = 0,0019

δ1 = 0,108 °= 6'29"

8. Проведем аналогичные расчеты A1B для изобретения, предложенного в аналогичной патентной заявке США US7990620 B2 от 02.08.2011:

A1B = (C1B * A1A)/(C1B+CB)= (720 * 5.77)/(720+15) = 5.65 мм

Применяя закон синусов к треугольнику ∆C1BA1, получаем:

sin(δ1) = (A1B * sin⁡(η1))/(C1B)=(5,65 * sin⁡(41°))/720 = 0,0051

δ1 = 0,29 ° = 17'24"

Сравним результаты пунктов 8 и 9:

Раздвоение изображения созданного методом приведенном в заявляемом изобретении составляет 2.1 мм (см. пункт 8), при этом угол расхождения двоящихся элементов δ1 составляет 6'29".

Раздвоение изображения в аналогичной патентной заявке США US7990620 B2 от 02.08.2011 составляет 5.65мм, при этом угол расхождения двоящихся элементов δ1 составляет 17'24", что в 2.7 раза больше, чем в методе заявляемого изобретения.

Поскольку удаленность реального изображения от лобового стекла для встраиваемых систем Garmin (см. [1]) и Defi (см. [2]) приблизительно равна удаленности реального изображения в методе, заявленном в патентной заявке США US7990620 B2 от 02.08.2011, расчет степени раздвоения дали бы результат аналогичный п.9, то есть раздвоение на уровне 5.65мм. Именно поэтому в системах Garmin (см. [1]) и Defi (см. [2]) необходимо использовать специальные отражающие элементы (стекла и пленки) для создания нормального читабельного изображения.

Фиг.4 соответствует выше упомянутым встраиваемым системам HUD Garmin, Defi.

Фиг.5 соответствует текущему заявляемому изобретению метода создания мнимого изображения для системы HUD.

Исследования показали, что отражения от лобового стекла в области 5 (см. фиг.1 и фиг.2) происходят под углами близкими к углу Брюстера. При этом эффективное отражение от лобового стекла при этих углах имеет горизонтально-поляризованный (s-polarized) свет.
На фиг.6 показан график процентной доли отражения горизонтально-поляризованного и вертикально-поляризованного лучей. Из графика видно, что вертикально-поляризованный (p-polarized) имеет очень низкий процент отражения на углах, близких к углу Брюстера.
А при угле Брюстера падающий световой поток 9 при отражении становится полностью горизонтально-поляризованным 10 (см. фиг.7). Это означает, что источник изображения должен быть горизонтально поляризованным, поскольку вертикально-поляризованная составляющая не участвует в формировании итогового изображения на лобовом стекле, но при этом снижается на 55% уровень засветки передней панели и приборной панели, что очень важно для работы системы в ночное время.

На фиг.8 изображено устройство 3 в профиль. На дисплей 12 наклеен горизонтально-ориентированный поляризоид . Из дисплея выходит горизонтально-поляризованный световой поток 13.

На фиг.9 изображен отражающий элемент, который представляет собой оптическое или промышленное зеркало 15 на подставке 16, на зеркало может быть наклеена поляризующая плена с горизонтальной поляризацией 14. Такой отражающий элемент отражает 98% света от источника изображения, но задерживает около 60% света попадающего на него через лобовое стекло. Это позволяет не камуфлировать отражающий элемент, при этом он не создает бликов и ярких отражений от источников света за пределами автомобиля.

Если требуется создать мнимое изображение для нескольких пассажиров, то для каждого пассажира устанавливается и настраивается отдельный отражательный элемент.

Для полного отражения реального изображения, размер отражающего элемента может быть приблизительно вдвое меньше чем размер источника изображения.

На фиг.10 и фиг.11 изображены возможные варианты конструкций изготовления передней панели 11 со встроенным отражающим элементом 12 для системы HUD при промышленном встраивании системы в автомобили. Плоскости вращения отражающего элемента обозначены цифрами 13 и 14.

Для того, чтобы закамуфлировать остаточные раздвоения изображения, необходимо использовать специальные шрифты при выводе текстовой информации. Текстовые символы не должны содержать сильно скругленных элементов и косых линий, но должны содержать прямоугольные элементы, либо быть достаточно толстыми, чтобы раздвоения не были заметны. На фиг.12 показано раздвоение обычного символа со скруглениями.

На фиг.13 показан пример цифр с прямоугольными элементами. Горизонтальные линии символов вдвое уже вертикальных линий.

На фиг.14 представлен пример раздвоения цифр с прямоугольными элементами.

Поскольку степень раздвоения изображения зависит от геометрических размеров лобового стекла, расположения отражательного элемента и источника изображения, программное обеспечение источника изображения должно иметь возможность менять толщину шрифта, чтобы горизонтальные линии символов точно касались, без просветов и перекрытий.

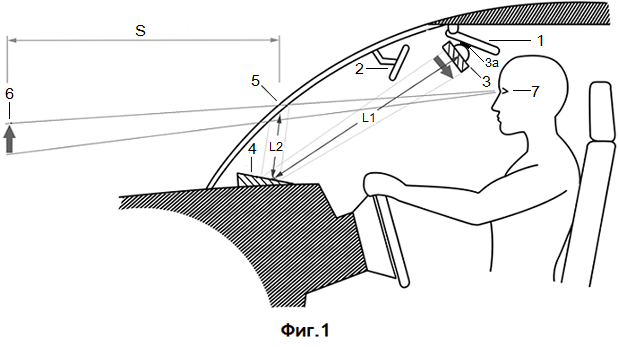
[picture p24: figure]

Приложение 1:


Ссылки:

1. Ссылки на сайт с примером встраиваемой системы HUD производства фирмы Garmin: http://www.garmin.ru/about/posts/20353/

http://gps-club.ru/gps_think/detail.php?ID=98709

2. Ссылка на сайт с примером встраиваемой системы HUD производства фирмы Defi:

http://www.defi-shop.ru/index.php?id=55

3. Ссылка на сайт с примером встраиваемой системы HUD производства фирмы Pioneer: http://www.pioneer-rus.ru/ru/products/25/111/241/SPX-HUD01/page.html

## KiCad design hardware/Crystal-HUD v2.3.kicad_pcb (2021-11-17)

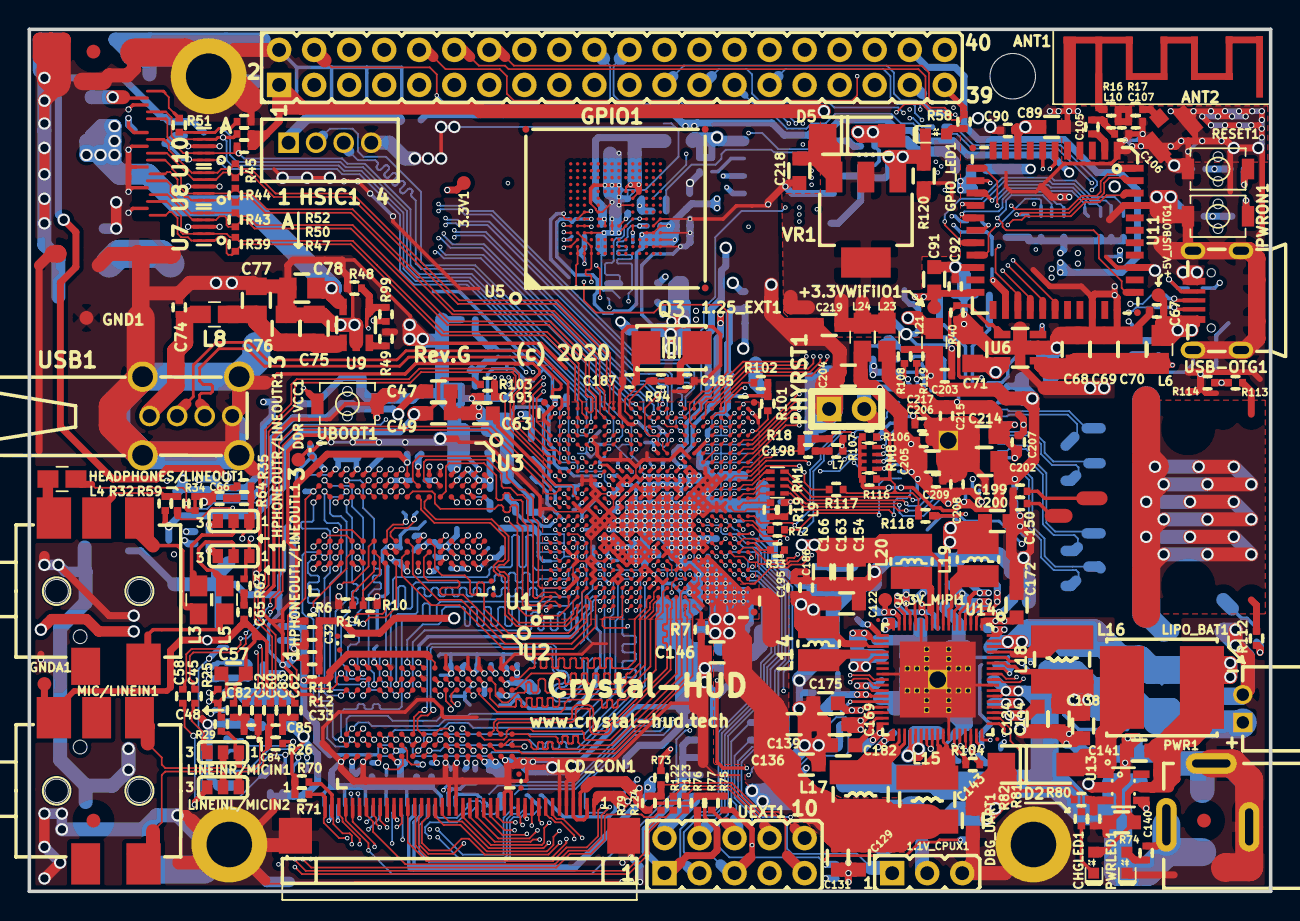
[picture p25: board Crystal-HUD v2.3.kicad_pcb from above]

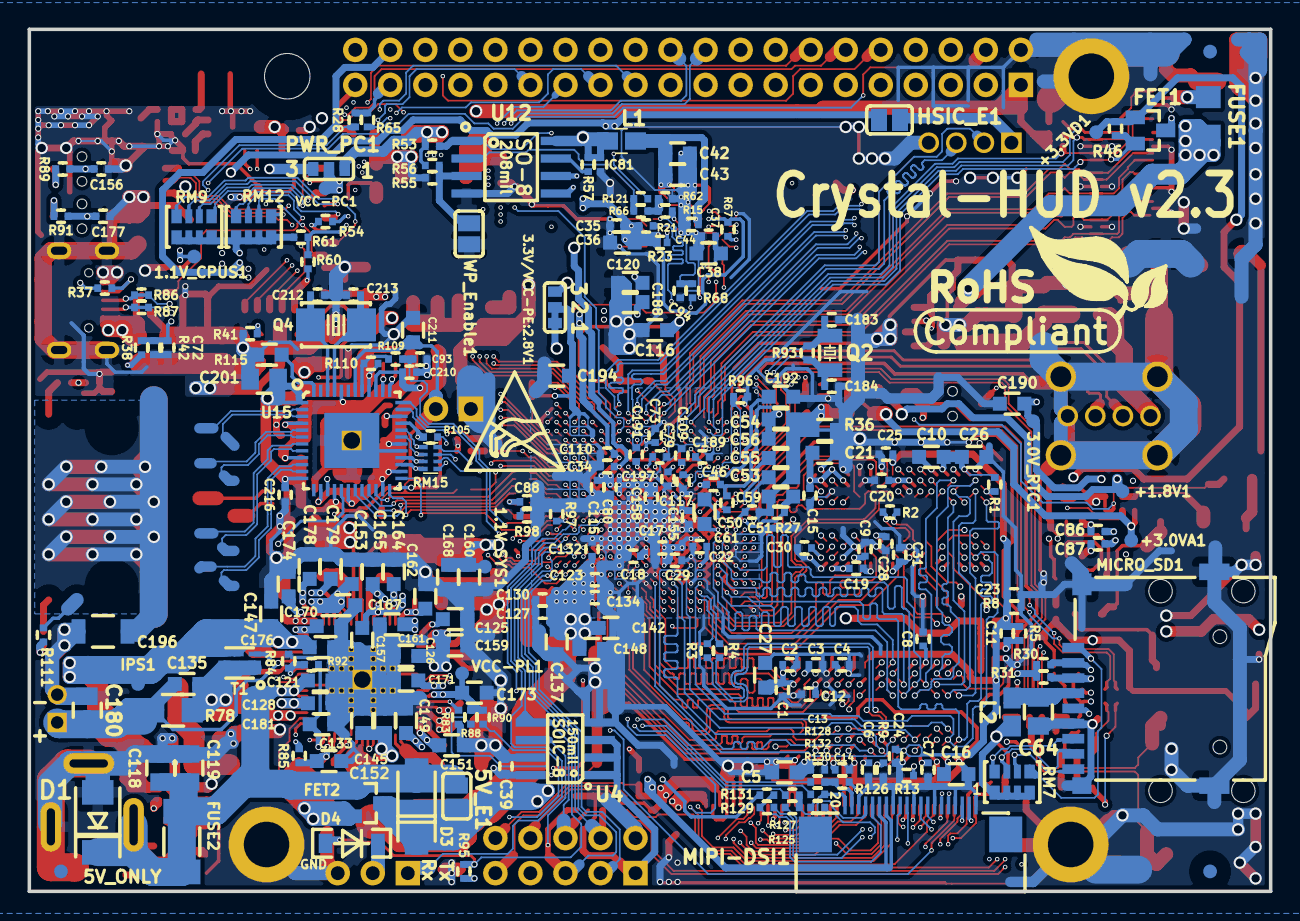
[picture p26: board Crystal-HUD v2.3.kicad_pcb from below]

Board: 6 copper layers, 90.0 x 62.5 mm, 445 parts (229 on the bottom side), 396 nets.

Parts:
1.1V_CPUS1, 1.1V_CPUX1, 1.1V_SYS1, 1.25_EXT1, 3.0V_RTC1, 3.3V1, 3.3V_MIPI1: TESTPAD; TP_SMD
3.3V/VCC-PE:2.8V1: Opened(2-3);Closed(1-2); SJ_2_SMALL_12_TIED
5V_E1: Opened; SJ
+1.8V1, +3.0VA1, +3.3VD1, +3.3VWiFiIO1, +5V_USBOTG1: TESTPAD; TP_SMD
ANT1: PCB_WIFI_ANT; BT_Antenna_Inverted_1ANT_2GND
ANT2: NA(U.FL-R-SMT-1); U.FL-R-SMT-1
C1, C2, C3, C4, C6, C7, C8, C9, C11, C12, C13, C14, C15, C17, C18, C19, C20, C22, C23, C24, C25, C32, C33, C34, C45, C46, C50, C51, C52, C58, C60, C65, C66, C67, C72, C73, C74, C79, C80, C82, C83, C86, C87, C109, C110, C115, C117, C123, C127, C130, C132, C134, C155, C156, C158, C177, C186, C189, C191, C195, C197, C199, C200, C203, C206, C207, C208, C209, C210, C215, C216, C217: 100nF\10V/10%; C_0402_5MIL_DWS
C5, C10, C16, C21, C47, C49, C53, C54, C57, C59, C63, C116, C121, C122, C124, C125, C126, C128, C129, C131, C133, C136, C138, C139, C140, C141, C143, C144, C145, C146, C147, C148, C149, C150, C151, C152, C153, C154, C157, C159, C161, C162, C164, C165, C166, C167, C168, C169, C170, C171, C172, C173, C175, C176, C178, C179, C188, C192, C194: 10uF\6.3V/20%; C_0603_5MIL_DWS
C26: 10uF/6.3V/20%; C_0603_5MIL_DWS
C27: 1uF/10V/10%; C_0603_5MIL_DWS
C28, C29, C30, C31, C39: 100nF/10V/10%; C_0402_5MIL_DWS
C35, C37, C44, C81, C90, C92: NA(100nF\10V/10%); C_0402_5MIL_DWS
C36, C38, C43: NA(2.2uF\6.3V/10%); C_0603_5MIL_DWS
C42: NA(22uF\6.3V/20%); C_0603_5MIL_DWS
C48, C62, C84, C85, C185, C187, C212, C213: 33pF\50V/5%; C_0402_5MIL_DWS
C55, C120, C135, C137, C142, C160, C163, C181, C182, C190, C211: 1uF\10V/10%; C_0603_5MIL_DWS
C56, C61: 2.2uF\6.3V/10%; C_0603_5MIL_DWS
C64, C68, C71, C75, C78, C118, C119, C180, C201, C202: 47uF\6.3V/20%; C_0805_5MIL_DWS
C69, C70, C76, C77: NA(47uF\6.3V/20%); C_0805_5MIL_DWS
C88, C198: NA(24pF\50V/5%); C_0402_5MIL_DWS
C89, C91, C174: NA(10uF\6.3V/20%); C_0603_5MIL_DWS
C93: 24pF\50V/5%; C_0402_5MIL_DWS
C94: NA; C_0402_5MIL_DWS
C105: NA(10pF\50V/5%); C_0402_5MIL_DWS
C106: NA(0.8pF\C0402); C_0402_5MIL_DWS
C107: NA(1.5pF\C0402); C_0402_5MIL_DWS
C183, C184: 22pF\50V/5%; C_0402_5MIL_DWS
C193: NA(1nF\50V/10%); C_0402_5MIL_DWS
C196: 1nF\2kV/10%/X7R; C_1206_5MIL_DWS_ISO
C204, C205, C214, C218, C219: 22uF\6.3V/20%; C_0603_5MIL_DWS
CHGLED1: LED\YELLOW/0603; LED_0603_KA
D1: SMBJ6.0A; DO214AA_1(K)-2(A)
D2, D3: 1N5822\SS34/SMA; SMA-KA
D4: 1N5819(S4SOD-123); SOD-123_1C-2A_KA
D5: 1N4007\SMA; SMA-KA
DBG_UART1: HN1x3
DDR-VCC1: TESTPAD; TP_SMD
FET1: BSS138(SOT23-3); SOT23
FET2: IRLML6402(SOT-23); SOT23
FID1, FID2, FID3, FID4, FID5, FID6: Fiducial1x3_transp
FUSE1: FSMD035; FUSE-1206
FUSE2: NA(5025); FUSE-5025
GND1: TESTPAD; TP_SMD
GNDA1: TESTPAD; TESTPAD_40-ROUND
GPIO1: NA(HN2x20); HN2x20
GPIO_LED1: LED\Red/0603; LED_0603_KA
HEADPHONES/LINEOUT1: SCJ325P00XG0B02G
HPHONEOUTL/LINEOUTL1: Soldered(1-2);Opened(2-3); SJ_2_SMALL
HPHONEOUTR/LINEOUTR1: Soldered(1-2);Opened(2-3); SJ_2_SMALL
HSIC1: NA(B4B-PH-K-S); B4B-PH-K-S
HSIC_E1: Opened; SJ
IPS1: TESTPAD; TP_SMD
L1: NA(FB0805\600R/2A); L_0805_5MIL_DWS
L2, L3, L4, L5, L6, L8, L21, L23, L24: FB0805\600R/2A; L_0805_5MIL_DWS
L7, L9: NA(2.7nH\L0402); L_0402_5MIL_DWS
L10: NA(3.3nH +-0.1nH LQP15MN3N3B02D); L_0402_5MIL_DWS
L14, L19, L20: SWPA3015S1R5NT(1.5uH\2.30A/DCR<0.1R/CD32); CD32
L15, L17, L18: SWPA4018S1R5NT(1.5uH\3.35A/DCR<0.1R/CD43); CD42(43)
L16: 2.2uH\3A/YS75/7x8; YS75_7X8MM
LCD_CON1: FPV-WZA21-40-LF
LINEINL/MICIN2: Opened(2-3);Soldered(1-2); SJ_2_SMALL
LINEINR/MICIN1: Opened(2-3);Soldered(1-2); SJ_2_SMALL
LIPO_BAT1: DW02R; LIPO_BAT-CON2DW02R
MIC/LINEIN1: SCJ325P00XG0B02G
MICRO_SD1: MICRO_SD(TFC-WPAPR-08); TFC-WPAPR-08
MIPI-DSI1: FPV-WZA21-20-LF
Mounting_hole1, Mounting_hole2, Mounting_hole3: Mounting_hole; Mounting_hole_3.3mm_with_5.5mm_pad
Mounting_hole4: Mounting_hole; Mounting_hole_3.3mm
PHYRST1: HN1x2(Opened); HN1x2_Jumper
PWR1: PWRJ-2mm(YDJ-1134)
PWRLED1: LED\Red/0603; LED_0603_KA
PWRON1: IT-1185AU2-160G-G-TR; IT1185AU2_V2
PWR_PC1: Opened(2-3);Soldered(1-2); SJ_2_SMALL
Q2: Q32.768kHz/12.5pF/2P/SMD1206; CM7V-T1A(Crystal_Package-1206_3.20x1.50x0.65mm)
Q3: Q24MHZ\20pF/20ppm/2P/5x3.2mm; HCX-4S_2Pins_5.0x3.2mm_TEST
Q4: Q25MHz\20pF/20ppm/2P/5x3.2mm; HCX-4S_2Pins_5.0x3.2mm_TEST
R1, R5, R8, R11, R12, R26, R29: 2k\1%; R_0402_5MIL_DWS
R2: 100R\1%; R_0402_5MIL_DWS
R3, R4, R18, R19, R33, R63, R64, R65, R72, R105, R109, R121, R122, R123, R124, R125, R126, R129, R130: 22R; R_0402_5MIL_DWS
R6, R55, R84, R96, R97, R98, R118, R127, R128, R131, R132: NA; R_0402_5MIL_DWS
R7, R9, R10: 243R\1%; R_0402_5MIL_DWS
R13, R14: NA(243R\1%); R_0402_5MIL_DWS
R15, R54, R66, R68, R73: NA(22R); R_0402_5MIL_DWS
R16: 0R; R_0402_5MIL_DWS
R17, R60: NA(0R); R_0402_5MIL_DWS
R21, R23, R48, R53, R56, R57, R61, R62, R67, R104: NA(10k); R_0402_5MIL_DWS
R25: 470R; R_0402_5MIL_DWS
R27: 200k\1%; R_0402_5MIL_DWS
R28: NA(1k); R_0402_5MIL_DWS
R30, R35, R103, R116: 100k; R_0402_5MIL_DWS
R31, R37, R40, R42, R52, R76, R79, R83, R85, R95, R99, R106, R119: 10k; R_0402_5MIL_DWS
R32: NA(1M); R_0402_5MIL_DWS
R34, R86, R87, R94: 0R(Board_Mounted); R_0402_5MIL_0R(Board_Mounted)
R36: 0R(Board_Mounted); R_0603_5MIL_0R(Board_Mounted)
R38, R51: 4.7k; R_0402_5MIL_DWS
R39, R43, R44, R45: NA(510R); R_0402_5MIL_DWS
R41: 13k\1%; R_0402_5MIL_DWS
R46: 27k; R_0402_5MIL_DWS
R47, R50, R70, R71, R74, R75, R77, R82, R88, R90: 2.2k; R_0402_5MIL_DWS
R49: 3.92k\1%; R_0402_5MIL_DWS
R58, R89, R91, R92, R107, R108, R110, R111, R112, R113, R114, R117: 1k; R_0402_5MIL_DWS
R59: 47k; R_0402_5MIL_DWS
R78: 0.01R\1%/1206; R_1206_5MIL_DWS
R80: 8.25k\1%; R_0402_5MIL_DWS
R81: 1.1k\1%; R_0402_5MIL_DWS
R93: 10M; R_0402_5MIL_DWS
R101, R102: NA(2.2k); R_0402_5MIL_DWS
R115: 12.1k\1%; R_0603_5MIL_DWS
R120: 120R; R_0603_5MIL_DWS
RESET1: IT-1185AU2-160G-G-TR; IT1185AU2_V2
RM1, RM15: RA0805_(4X0402)_22R; RA0805_(4X0402)_xx_BIGGEROUTPADS
RM7: RA1206_(4x0603)_4B8_100k; RA1206_(4X0603)_4B8_xx
RM8: RA0805_(4X0402)_4.7k; RA0805_(4X0402)_xx_BIGGEROUTPADS
RM9, RM12: NA(RA1206_(4x0603)_4B8_100k); RA1206_(4X0603)_4B8_xx
Sign-Antistatic: LOGO_ANTISTATIC_1
Sign-RoHS: LOGO_ROHS_1
T1: WPM1481-6\TR(DFN2X2-6L); DFN2x2-6L
U1: AllWinner-A64(FBGA396); FBGA396
U2, U3: K4B4G1646Q-HYK0(FBGA-96_256Mx16_DDR3-1600_11-11-1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; FBGA96(HYNIX_SAMSUNG_512MX16_DDR3)
U4: AT24C16C-SSHM-T(SOIC-8_150mil); SOIC-8_150mil
U5: NA(KLMAG2GEND-B031(FBGA153)); FBGA153_Pitch-0.5mm_Ball-0.25mm_Dimensions-11.50x13.00x0.80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
U6, U9: SY6280AAC(SOT23-5); SOT-23-5
U7, U8, U10: NA(RCLAMP0524P(SLP2510P8)); SLP2510P8_TEST
U11: NA(RTL8723BS(ComboModule)); RL-SM02BD(RTL8723BS)
U12: NA(W25Q128FVSIG); SO-8_208mil
U13: MT3608(SOT23-6); SOT23-6
U14: AXP803(QFN68_8x8mm); QFN68
U15: KSZ9031RNXCC(QFN48_1DRILL(PADPITCH-0.5MM)); QFN48_1DRILL(PADPITCH-0.5MM)
UBOOT1: IT-1185AU2-160G-G-TR; IT1185AU2_V2
UEXT1: HN2x5
USB1: USB_A_VERTICAL; USB_A_VERTICAL_PTH
USB-OTG1: MICRO_USB\MISB-SWMM-5B_LF; USB-MICRO_MISB-SWMM-5B_LF
VCC-PC1: TESTPAD; TP_SMD
VCC-PL1: TESTPAD; TP_SMD
VR1: AMS1117(ADJ); SOT223
WP_Enable1: Opened; SJ

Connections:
1.1V_CPUS: 1.1V_CPUS1.1, C117.2, C120.2, C179.2, U1.H15, U14.5
1.1V_CPUX: 1.1V_CPUX1.1, C123.2, C127.2, C129.2, C130.2, C131.2, C132.2, C134.2, C136.2, C137.2, C139.2, C142.2, C146.2, C148.2, L15.2, L17.2, U1.AA1, U1.AA3, U1.AB2, U1.AC1, U1.AC2, U1.U6, U1.V2, U1.V3, U1.V4, U1.V5, U1.V6, U1.W1, U1.W3, U1.W4, U1.W5, U1.Y2, U1.Y3, U1.Y4
1.1V_SYS: 1.1V_SYS1.1, C154.2, C155.2, C158.2, C160.2, C163.2, C166.2, C168.2, L20.2, U1.J12, U1.J13, U1.K14, U1.L13, U1.L14, U1.M13, U1.M14, U1.N14, U1.P14, U1.R13, U1.R14, U1.T15, U14.9
1.2V_HSIC: C178.2, C197.1, HSIC_E1.1, U1.K16, U14.3
3.0V_RTC: 3.0V_RTC1.1, C152.1, C189.2, C190.2, R85.2, R104.1, U1.H16, U14.49
+1.5V: C1.1, C2.1, C3.1, C4.1, C5.1, C6.1, C7.1, C8.1, C9.1, C10.1, C11.1, C12.1, C13.1, C14.1, C15.1, C16.1, C17.1, C18.1, C19.1, C20.1, C21.1, C26.1, C27.1, C28.1, C29.1, C30.1, C31.1, C32.2, C150.2, DDR-VCC1.1, L19.2, R1.2, R5.2, R11.2, U1.G7, U1.G8, U1.G9, U1.J8, U1.K6, U1.K7, U1.L6, U1.L7, U1.L8, U1.N7, U1.N8, U2.A1, U2.A8, U2.B2, U2.C1, U2.C9, U2.D2, U2.D9, U2.E9, U2.F1, U2.G7, U2.H2, U2.H9, U2.K2, U2.K8, U2.N1, U2.N9, U2.R1, U2.R9, U3.A1, U3.A8, U3.B2, U3.C1, U3.C9, U3.D2, U3.D9, U3.E9, U3.F1, U3.G7, U3.H2, U3.H9, U3.K2, U3.K8, U3.N1, U3.N9, U3.R1, U3.R9, U14.8
+1V8: +1.8V1.1, C47.2, C50.2, C170.2, PWR_PC1.3, U1.E13, U14.68
+3.0VA: +3.0VA1.1, C46.1, C49.1, C175.1, C191.2, R32.2, R103.1, U1.G14, U1.N16, U14.31
+3.3VD: +3.3VD1.1, C79.2, C161.2, FET1.1, R46.1, U1.M16, U14.17
+3.3VWiFiIO: +3.3VWiFiIO1.1, C91.2, C92.2, C110.2, C165.2, R61.2, RM9.1.1, RM9.2.1, RM9.3.1, RM9.4.1, RM12.1.1, RM12.2.1, RM12.3.1, RM12.4.1, U1.T17, U11.22, U14.13
+3V3: 3.3V1.1, 3.3V/VCC-PE:2.8V1.3, C39.1, C73.2, C80.1, C81.2, C89.2, C90.2, C115.2, C116.2, C122.2, C186.2, C195.2, D5.2, GPIO1.3, L1.1, L2.1, L14.2, L21.2, LCD_CON1.3, PWR_PC1.1, R30.2, R31.2, R37.2, R53.2, R56.2, R57.2, R70.2, R71.2, R75.1, R76.1, R77.1, R79.1, R95.2, R99.1, RM7.1.1, RM7.2.1, RM7.3.1, RM7.4.1, U1.L16, U1.N18, U1.N19, U1.T14, U1.U15, U1.U16, U4.1, U4.2, U4.3, U4.8, U11.9, U12.8, U13.4, U14.20, UEXT1.1
+5V: 5V_E1.2, C71.1, C78.1, D3.1, FET2.3, FUSE1.1, GPIO1.1, LCD_CON1.1, R47.1, R50.1, U6.5, U9.5
+5V_EXT: 5V_E1.1, C118.2, C119.2, C121.1, D1.1, D3.2, FET2.1, FUSE2.1, FUSE2.2, PWR1.+, R74.1, U14.57, U14.58
+5V_USBOTG: +5V_USBOTG1.1, C67.1, C124.1, L6.2, U14.54, USB-OTG1.1
/NAND Flash , eMMC, T-Card and Audio/HP-DET: R59.2, U1.D11
/NAND Flash , eMMC, T-Card and Audio/HPOUTFB: L4.1, R34.2, U1.C10
/NAND Flash , eMMC, T-Card and Audio/HPOUTL: HPHONEOUTL/LINEOUTL1.1, R63.2, U1.C13
/NAND Flash , eMMC, T-Card and Audio/HPOUTR: HPHONEOUTR/LINEOUTR1.1, R35.2, R64.2, U1.C12
/NAND Flash , eMMC, T-Card and Audio/LINEINL: C58.2, U1.B14
/NAND Flash , eMMC, T-Card and Audio/LINEINR: C45.2, U1.A14
/NAND Flash , eMMC, T-Card and Audio/LINEOUTL: C87.1, U1.D16
/NAND Flash , eMMC, T-Card and Audio/LINEOUTR: C86.1, U1.C16
/NAND Flash , eMMC, T-Card and Audio/MBIAS: R25.2, U1.E14
/NAND Flash , eMMC, T-Card and Audio/MICIN1N: C82.2, U1.B16
/NAND Flash , eMMC, T-Card and Audio/MICIN1P: C52.2, U1.B15
/NAND Flash , eMMC, T-Card and Audio/MICIN2N: C83.2, U1.A17
/NAND Flash , eMMC, T-Card and Audio/MICIN2P: C60.2, U1.B17
/NAND Flash , eMMC, T-Card and Audio/NAND0-ALE\SDC2-DS: R15.2, R62.1, R66.2, U1.K18
/NAND Flash , eMMC, T-Card and Audio/NAND0-DQ0\SDC2-D0: R67.1, U1.M21, U5.A3
/NAND Flash , eMMC, T-Card and Audio/NAND0-DQ1\SDC2-D1: U1.L19, U5.A4
/NAND Flash , eMMC, T-Card and Audio/NAND0-DQ2\SDC2-D2: U1.K20, U5.A5
/NAND Flash , eMMC, T-Card and Audio/NAND0-DQ3\SDC2-D3: U1.H20, U5.B2
/NAND Flash , eMMC, T-Card and Audio/NAND0-DQ4\SDC2-D4: U1.P18, U5.B3
/NAND Flash , eMMC, T-Card and Audio/NAND0-DQ5\SDC2-D5: U1.L20, U5.B4
/NAND Flash , eMMC, T-Card and Audio/NAND0-DQ6\SDC2-D6: U1.J21, U5.B5
/NAND Flash , eMMC, T-Card and Audio/NAND0-DQ7\SDC2-D7: U1.R21, U5.B6
/NAND Flash , eMMC, T-Card and Audio/NAND0-DQS\SDC2-RST: R23.1, U1.N20, U5.K5
/NAND Flash , eMMC, T-Card and Audio/NAND0-RB0\SDC2-CMD: R21.1, U1.K19, U5.M5
/NAND Flash , eMMC, T-Card and Audio/NAND0-RE\SDC2-CLK: R68.2, U1.G20
/NAND Flash , eMMC, T-Card and Audio/SDC0-CLK: R33.2, U1.AC8
/NAND Flash , eMMC, T-Card and Audio/SDC0-CMD: MICRO_SD1.3, R31.1, U1.W9
/NAND Flash , eMMC, T-Card and Audio/SDC0-D0: MICRO_SD1.7, RM7.1.2, U1.W13
/NAND Flash , eMMC, T-Card and Audio/SDC0-D1: MICRO_SD1.8, RM7.2.2, U1.AB10
/NAND Flash , eMMC, T-Card and Audio/SDC0-D2: MICRO_SD1.1, RM7.4.2, U1.AB9
/NAND Flash , eMMC, T-Card and Audio/SDC0-D3: MICRO_SD1.2, R30.1, U1.AB6
/NAND Flash , eMMC, T-Card and Audio/SDC0-DET#: MICRO_SD1.9, RM7.3.2, U1.AB8
/NAND Flash , eMMC, T-Card and Audio/eMMC_CLK: C94.1, R68.1, U5.M6
/Power Supply, Extensions and MiPi-DSI/1.8V_DVDD-CSI: C172.2, GPIO1.36, U14.1
/Power Supply, Extensions and MiPi-DSI/2.8V_AVDD-CSI: C164.2, GPIO1.38, U14.14
/Power Supply, Extensions and MiPi-DSI/3.3V_MIPI: 3.3V_MIPI1.1, C162.2, MIPI-DSI1.14, MIPI-DSI1.15, U14.16
/Power Supply, Extensions and MiPi-DSI/DC5SET: R84.2, R92.1, U14.62
/Power Supply, Extensions and MiPi-DSI/DSI-CKN: MIPI-DSI1.5, U1.P23
/Power Supply, Extensions and MiPi-DSI/DSI-CKP: MIPI-DSI1.6, U1.N23
/Power Supply, Extensions and MiPi-DSI/DSI-D0N: MIPI-DSI1.8, U1.T23
/Power Supply, Extensions and MiPi-DSI/DSI-D0P: MIPI-DSI1.9, U1.T22
/Power Supply, Extensions and MiPi-DSI/DSI-D1N: MIPI-DSI1.2, U1.R22
/Power Supply, Extensions and MiPi-DSI/DSI-D1P: MIPI-DSI1.3, U1.P22
/Power Supply, Extensions and MiPi-DSI/DSI-D2N: R126.2, U1.N22
/Power Supply, Extensions and MiPi-DSI/DSI-D2P: R130.1, U1.M22
/Power Supply, Extensions and MiPi-DSI/DSI-D3N: R129.1, U1.L22
/Power Supply, Extensions and MiPi-DSI/DSI-D3P: R125.2, U1.L23
/Power Supply, Extensions and MiPi-DSI/MIPI-DSI-BKL: R132.1, U1.W8
/Power Supply, Extensions and MiPi-DSI/MIPI-DSI-EN: R128.2, U1.Y6
/Power Supply, Extensions and MiPi-DSI/MIPI-DSI-RST: R127.2, U1.AA6
/Power Supply, Extensions and MiPi-DSI/PB0: GPIO1.10, U1.V9
/Power Supply, Extensions and MiPi-DSI/PB1: GPIO1.12, U1.AB7
/Power Supply, Extensions and MiPi-DSI/PB2: GPIO1.14, U1.W10
/Power Supply, Extensions and MiPi-DSI/PB3: GPIO1.16, U1.AA7
/Power Supply, Extensions and MiPi-DSI/PB4: GPIO1.18, U1.W7
/Power Supply, Extensions and MiPi-DSI/PE0: GPIO1.5, U1.AA18
/Power Supply, Extensions and MiPi-DSI/PE1: GPIO1.7, U1.AB23
/Power Supply, Extensions and MiPi-DSI/PE2: GPIO1.9, U1.AA22
/Power Supply, Extensions and MiPi-DSI/PE3: GPIO1.11, U1.AA21
/Power Supply, Extensions and MiPi-DSI/PE4: GPIO1.13, U1.AA19
/Power Supply, Extensions and MiPi-DSI/PE5: GPIO1.15, U1.W17
/Power Supply, Extensions and MiPi-DSI/PE6: GPIO1.17, U1.W20
/Power Supply, Extensions and MiPi-DSI/PE7: GPIO1.19, U1.Y19
/Power Supply, Extensions and MiPi-DSI/PE8: GPIO1.21, U1.AC22
/Power Supply, Extensions and MiPi-DSI/PE9: GPIO1.23, U1.Y17
/Power Supply, Extensions and MiPi-DSI/PE10: GPIO1.25, U1.AB22
/Power Supply, Extensions and MiPi-DSI/PE11: GPIO1.27, U1.W21
/Power Supply, Extensions and MiPi-DSI/PE12: GPIO1.29, U1.AB20
/Power Supply, Extensions and MiPi-DSI/PE13: GPIO1.31, U1.Y22
/Power Supply, Extensions and MiPi-DSI/PE14: GPIO1.33, R101.1, U1.AC20
/Power Supply, Extensions and MiPi-DSI/PE15: GPIO1.35, R102.1, U1.Y23
/Power Supply, Extensions and MiPi-DSI/PE16: R65.2, U1.AB21
/Power Supply, Extensions and MiPi-DSI/PE16\POWERON: GPIO1.37, R28.1, R65.1
/Power Supply, Extensions and MiPi-DSI/PE17\GPIO_LED: GPIO1.39, R58.1, U1.W22
/Power Supply, Extensions and MiPi-DSI/UEXT-CLK: R122.1, UEXT1.9
/Power Supply, Extensions and MiPi-DSI/UEXT-CS: R73.2, R79.2, R124.2, UEXT1.10
/Power Supply, Extensions and MiPi-DSI/UEXT-MISO: R121.1, UEXT1.7
/Power Supply, Extensions and MiPi-DSI/UEXT-MOSI: R123.2, UEXT1.8
/S0SA0: U1.P5, U2.N3, U3.N3
/S0SA1: U1.R4, U2.P7, U3.P7
/S0SA2: U1.N5, U2.P3, U3.P3
/S0SA3: U1.N6, U2.N2, U3.N2
/S0SA4: U1.P6, U2.P8, U3.P8
/S0SA5: U1.G4, U2.P2, U3.P2
/S0SA6: U1.F3, U2.R8, U3.R8
/S0SA7: U1.E4, U2.R2, U3.R2
/S0SA8: U1.D3, U2.T8, U3.T8
/S0SA9: U1.C4, U2.R3, U3.R3
/S0SA10: U1.M4, U2.L7, U3.L7
/S0SA11: U1.U4, U2.R7, U3.R7
/S0SA12: U1.K5, U2.N7, U3.N7
/S0SA13: U1.E8, U2.T3, U3.T3
/S0SA14: U1.K4, U2.T7, U3.T7
/S0SA15: U1.T4, U2.M7, U3.M7
/S0SBA0: U1.D8, U2.M2, U3.M2
/S0SBA1: U1.R3, U2.N8, U3.N8
/S0SBA2: U1.C6, U2.M3, U3.M3
/S0SCAS: U1.C9, U2.K3, U3.K3
/S0SCKE0: U1.J3, U2.K9, U3.K9
/S0SCKE1: U1.H6, U2.J9, U3.J9
/S0SCK_N: R2.1, R4.1, U2.K7, U3.K7
/S0SCK_P: R2.2, R3.1, U2.J7, U3.J7
/S0SCS0: U1.E5, U2.L2, U3.L2
/S0SCS1: U1.H5, U2.L1, U3.L1
/S0SDQ0: U1.L3, U2.F7
/S0SDQ1: U1.G1, U2.G2
/S0SDQ2: U1.H3, U2.F2
/S0SDQ3: U1.K1, U2.H7
/S0SDQ4: U1.H2, U2.E3
/S0SDQ5: U1.H1, U2.H3
/S0SDQ6: U1.L1, U2.H8
/S0SDQ7: U1.L2, U2.F8
/S0SDQ8: U1.T3, U2.A7
/S0SDQ9: U1.T2, U2.C8
/S0SDQ10: U1.T1, U2.B8
/S0SDQ11: U1.R2, U2.D7
/S0SDQ12: U1.N3, U2.A3
/S0SDQ13: U1.N2, U2.C2
/S0SDQ14: U1.N1, U2.C3
/S0SDQ15: U1.M2, U2.A2
/S0SDQ16: U1.E3, U3.F7
/S0SDQ17: U1.F2, U3.H8
/S0SDQ18: U1.E2, U3.H7
/S0SDQ19: U1.E1, U3.F8
/S0SDQ20: U1.B1, U3.H3
/S0SDQ21: U1.B2, U3.F2
/S0SDQ22: U1.A2, U3.E3
/S0SDQ23: U1.B3, U3.G2
/S0SDQ24: U1.C5, U3.A7
/S0SDQ25: U1.B4, U3.C8
/S0SDQ26: U1.A4, U3.D7
/S0SDQ27: U1.A5, U3.B8
/S0SDQ28: U1.A7, U3.A3
/S0SDQ29: U1.A8, U3.C3
/S0SDQ30: U1.B8, U3.A2
/S0SDQ31: U1.B9, U3.C2
/S0SDQM0: U1.J2, U2.E7
/S0SDQM1: U1.P3, U2.D3
/S0SDQM2: U1.C2, U3.E7
/S0SDQM3: U1.B7, U3.D3
/S0SDQS0_N: U1.K2, U2.G3
/S0SDQS0_P: U1.K3, U2.F3
/S0SDQS1_N: U1.P2, U2.B7
/S0SDQS1_P: U1.P1, U2.C7
/S0SDQS2_N: U1.D1, U3.G3
/S0SDQS2_P: U1.D2, U3.F3
/S0SDQS3_N: U1.B5, U3.B7
/S0SDQS3_P: U1.B6, U3.C7
/S0SODT0: U1.D5, U2.K1, U3.K1
/S0SODT1: U1.E7, U2.J1, U3.J1
/S0SRAS: U1.F7, U2.J3, U3.J3
/S0SRST: R1.1, U1.D10, U2.T2, U3.T2
/S0SVREF: C22.2, C32.1, C33.2, R6.2, R11.1, R12.2, U1.G5
/S0SWE: U1.C8, U2.L3, U3.L3
/USB&HDMI,WiFi&BT,Ethernet,LCD/1.25_EXT: 1.25_EXT1.1, C219.1, L23.2, L24.2, R120.1, VR1.2
/USB&HDMI,WiFi&BT,Ethernet,LCD/AP-WAKE-BT: U1.B20, U11.6
/USB&HDMI,WiFi&BT,Ethernet,LCD/BT-PCM-CLK: U1.AB18, U11.26
/USB&HDMI,WiFi&BT,Ethernet,LCD/BT-PCM-DIN: U1.AC19, U11.27
/USB&HDMI,WiFi&BT,Ethernet,LCD/BT-PCM-DOUT: U1.U22, U11.25
/USB&HDMI,WiFi&BT,Ethernet,LCD/BT-PCM-SYNC: U1.AB19, U11.28
/USB&HDMI,WiFi&BT,Ethernet,LCD/BT-RST-N: RM12.2.2, U1.A20, U11.34
/USB&HDMI,WiFi&BT,Ethernet,LCD/BT-UART-CTS: U1.AC17, U11.44
/USB&HDMI,WiFi&BT,Ethernet,LCD/BT-UART-RX: RM12.4.2, U1.AB17, U11.43
/USB&HDMI,WiFi&BT,Ethernet,LCD/BT-UART-TX: U1.U23, U11.42
/USB&HDMI,WiFi&BT,Ethernet,LCD/BT-WAKE-AP: U1.D19, U11.7
/USB&HDMI,WiFi&BT,Ethernet,LCD/EPHY-RST#: R117.2, U1.Y14
/USB&HDMI,WiFi&BT,Ethernet,LCD/GCLKIN\LCD_VSYNC: C93.2, LCD_CON1.30, R109.1, U1.AC11
/USB&HDMI,WiFi&BT,Ethernet,LCD/GMDC\LCD-PWM: LCD_CON1.36, U1.Y13, U15.36
/USB&HDMI,WiFi&BT,Ethernet,LCD/GMDIO\LCD_PWR: LCD_CON1.35, R108.1, U1.AC10, U15.37
/USB&HDMI,WiFi&BT,Ethernet,LCD/GRXCK\LCD_D18: C198.1, LCD_CON1.7, R18.1, U1.AC16
/USB&HDMI,WiFi&BT,Ethernet,LCD/GRXCTL\LCD_D19: LCD_CON1.8, R105.1, U1.AB16
/USB&HDMI,WiFi&BT,Ethernet,LCD/GRXD0\LCD_D15: LCD_CON1.20, RM15.1.2, U1.Y16
/USB&HDMI,WiFi&BT,Ethernet,LCD/GRXD1\LCD_D14: LCD_CON1.19, RM15.2.2, U1.W16
/USB&HDMI,WiFi&BT,Ethernet,LCD/GRXD2\LCD_D13: LCD_CON1.18, RM15.3.2, U1.AA13
/USB&HDMI,WiFi&BT,Ethernet,LCD/GRXD3\LCD_D12: LCD_CON1.17, RM15.4.2, U1.V17
/USB&HDMI,WiFi&BT,Ethernet,LCD/GTXCK\LCD_DE: L9.2, LCD_CON1.32, R19.2, U15.24
/USB&HDMI,WiFi&BT,Ethernet,LCD/GTXCTL\LCD_HSYNC: LCD_CON1.29, R72.2, U15.25
/USB&HDMI,WiFi&BT,Ethernet,LCD/GTXD0\LCD_CLK: LCD_CON1.31, RM1.2.1, U15.19
/USB&HDMI,WiFi&BT,Ethernet,LCD/GTXD1\LCD_D23: LCD_CON1.12, RM1.1.1, U15.20
/USB&HDMI,WiFi&BT,Ethernet,LCD/GTXD2\LCD_D22: LCD_CON1.11, RM1.3.1, U15.21
/USB&HDMI,WiFi&BT,Ethernet,LCD/GTXD3\LCD_D21: LCD_CON1.10, RM1.4.1, U15.22
/USB&HDMI,WiFi&BT,Ethernet,LCD/HCEC: FET1.2, R46.2, U1.F21, U10.1, U10.10
/USB&HDMI,WiFi&BT,Ethernet,LCD/HHPD: R51.1, R52.1, U1.E21, U10.5, U10.6
/USB&HDMI,WiFi&BT,Ethernet,LCD/HSCL: R47.2, U1.G21, U10.2, U10.9
/USB&HDMI,WiFi&BT,Ethernet,LCD/HSDA: R50.2, U1.E20, U10.4, U10.7
/USB&HDMI,WiFi&BT,Ethernet,LCD/HTX0N: R44.1, U1.G23, U8.2, U8.9
/USB&HDMI,WiFi&BT,Ethernet,LCD/HTX0P: R44.2, U1.G22, U8.1, U8.10
/USB&HDMI,WiFi&BT,Ethernet,LCD/HTX1N: R43.2, U1.F22, U7.5, U7.6
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

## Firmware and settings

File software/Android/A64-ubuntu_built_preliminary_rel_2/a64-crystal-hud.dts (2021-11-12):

/dts-v1/;

/memreserve/	0x0000000045000000 0x0000000000200000;
/memreserve/	0x0000000041010000 0x0000000000010000;
/memreserve/	0x0000000041020000 0x0000000000000800;
/memreserve/	0x0000000040100000 0x0000000000004000;
/memreserve/	0x0000000040104000 0x0000000000001000;
/memreserve/	0x0000000040105000 0x0000000000001000;
/ {
	model = "sun50iw1p1";
	compatible = "arm,sun50iw1p1", "arm,sun50iw1p1";
	interrupt-parent = <0x1>;
	#address-cells = <0x2>;
	#size-cells = <0x2>;

	clocks {
		compatible = "allwinner,sunxi-clk-init";
		device_type = "clocks";
		#address-cells = <0x2>;
		#size-cells = <0x2>;
		ranges;
		reg = <0x0 0x1c20000 0x0 0x320 0x0 0x1f01400 0x0 0xb0 0x0 0x1f00060 0x0 0x4>;

		losc {
			#clock-cells = <0x0>;
			compatible = "allwinner,fixed-clock";
			clock-frequency = <0x8000>;
			clock-output-names = "losc";
			linux,phandle = <0xc>;
			phandle = <0xc>;
		};

		iosc {
			#clock-cells = <0x0>;
			compatible = "allwinner,fixed-clock";
			clock-frequency = <0xf42400>;
			clock-output-names = "iosc";
			linux,phandle = <0xd>;
			phandle = <0xd>;
		};

		hosc {
			#clock-cells = <0x0>;
			compatible = "allwinner,fixed-clock";
			clock-frequency = <0x16e3600>;
			clock-output-names = "hosc";
			linux,phandle = <0x6>;
			phandle = <0x6>;
		};

		pll_cpu {
			#clock-cells = <0x0>;
			compatible = "allwinner,sunxi-pll-clock";
			lock-mode = "new";
			clock-output-names = "pll_cpu";
		};

		pll_audio {
			#clock-cells = <0x0>;
			compatible = "allwinner,sunxi-pll-clock";
			lock-mode = "new";
			assigned-clock-rates = <0x1770000>;
			clock-output-names = "pll_audio";
			linux,phandle = <0x2>;
			phandle = <0x2>;
		};

		pll_video0 {
			#clock-cells = <0x0>;
			compatible = "allwinner,sunxi-pll-clock";
			lock-mode = "new";
			assigned-clock-rates = <0x11b3dc40>;
			clock-output-names = "pll_video0";
			linux,phandle = <0x3>;
			phandle = <0x3>;
		};

		pll_ve {
			#clock-cells = <0x0>;
			compatible = "allwinner,sunxi-pll-clock";
			lock-mode = "new";
			clock-output-names = "pll_ve";
			linux,phandle = <0x16>;
			phandle = <0x16>;
		};

		pll_ddr0 {
			#clock-cells = <0x0>;
			compatible = "allwinner,sunxi-pll-clock";
			lock-mode = "new";
			clock-output-names = "pll_ddr0";
			linux,phandle = <0x93>;
			phandle = <0x93>;
		};

		pll_periph0 {
			#clock-cells = <0x0>;
			compatible = "allwinner,sunxi-pll-clock";
			lock-mode = "new";
			clock-output-names = "pll_periph0";
			linux,phandle = <0x4>;
			phandle = <0x4>;
		};

		pll_periph1 {
			#clock-cells = <0x0>;
			compatible = "allwinner,sunxi-pll-clock";
			lock-mode = "new";
			clock-output-names = "pll_periph1";
			linux,phandle = <0x5>;
			phandle = <0x5>;
		};

		pll_video1 {
			#clock-cells = <0x0>;
			compatible = "allwinner,sunxi-pll-clock";
			lock-mode = "new";
			assigned-clock-rates = <0x11b3dc40>;
			clock-output-names = "pll_video1";
		};

		pll_gpu {
			#clock-cells = <0x0>;
			compatible = "allwinner,sunxi-pll-clock";
			lock-mode = "new";
			clock-output-names = "pll_gpu";
			linux,phandle = <0x96>;
			phandle = <0x96>;
		};

		pll_mipi {
			#clock-cells = <0x0>;
			compatible = "allwinner,sunxi-pll-clock";
			lock-mode = "new";
			clock-output-names = "pll_mipi";
			linux,phandle = <0x8>;
			phandle = <0x8>;
		};

		pll_hsic {
			#clock-cells = <0x0>;
			compatible = "allwinner,sunxi-pll-clock";
			lock-mode = "new";
			clock-output-names = "pll_hsic";
			linux,phandle = <0x3a>;
			phandle = <0x3a>;
		};

		pll_de {
			#clock-cells = <0x0>;
			compatible = "allwinner,sunxi-pll-clock";
			lock-mode = "new";
			assigned-clock-rates = <0x11b3dc40>;
			clock-output-names = "pll_de";
			linux,phandle = <0x7>;
			phandle = <0x7>;
		};

		pll_ddr1 {
			#clock-cells = <0x0>;
			compatible = "allwinner,sunxi-pll-clock";
			lock-mode = "new";
			clock-output-names = "pll_ddr1";
			linux,phandle = <0x94>;
			phandle = <0x94>;
		};

		pll_audiox8 {
			#clock-cells = <0x0>;
			compatible = "allwinner,fixed-factor-clock";
			clocks = <0x2>;
			clock-mult = <0x8>;
			clock-div = <0x1>;
			clock-output-names = "pll_audiox8";
		};

		pll_audiox4 {
			#clock-cells = <0x0>;
			compatible = "allwinner,fixed-factor-clock";
			clocks = <0x2>;
			clock-mult = <0x8>;
			clock-div = <0x2>;
			clock-output-names = "pll_audiox4";
			linux,phandle = <0x3c>;
			phandle = <0x3c>;
		};

		pll_audiox2 {
			#clock-cells = <0x0>;
			compatible = "allwinner,fixed-factor-clock";
			clocks = <0x2>;
			clock-mult = <0x8>;
			clock-div = <0x4>;
			clock-output-names = "pll_audiox2";
		};

		pll_video0x2 {
			#clock-cells = <0x0>;
			compatible = "allwinner,fixed-factor-clock";
			clocks = <0x3>;
			clock-mult = <0x2>;
			clock-div = <0x1>;
			clock-output-names = "pll_video0x2";
		};

		pll_periph0x2 {
			#clock-cells = <0x0>;
			compatible = "allwinner,fixed-factor-clock";
			clocks = <0x4>;
			clock-mult = <0x2>;
			clock-div = <0x1>;
			clock-output-names = "pll_periph0x2";
			linux,phandle = <0x7b>;
			phandle = <0x7b>;
		};

		pll_periph1x2 {
			#clock-cells = <0x0>;
			compatible = "allwinner,fixed-factor-clock";
			clocks = <0x5>;
			clock-mult = <0x2>;
			clock-div = <0x1>;
			clock-output-names = "pll_periph1x2";
			linux,phandle = <0x5a>;
			phandle = <0x5a>;
		};

		pll_periph0d2 {
			#clock-cells = <0x0>;
			compatible = "allwinner,fixed-factor-clock";
			clocks = <0x4>;
			clock-mult = <0x1>;
			clock-div = <0x2>;
			clock-output-names = "pll_periph0d2";
		};

		hoscd2 {
			#clock-cells = <0x0>;
			compatible = "allwinner,fixed-factor-clock";
			clocks = <0x6>;
			clock-mult = <0x1>;
			clock-div = <0x2>;
			clock-output-names = "hoscd2";
		};

		cpu {
			#clock-cells = <0x0>;
			compatible = "allwinner,sunxi-periph-clock";
			clock-output-names = "cpu";
		};

		cpuapb {
			#clock-cells = <0x0>;
			compatible = "allwinner,sunxi-periph-clock";
			clock-output-names = "cpuapb";
		};

		axi {
			#clock-cells = <0x0>;
			compatible = "allwinner,sunxi-periph-clock";
			clock-output-names = "axi";
		};

		pll_periphahb0 {
			#clock-cells = <0x0>;
			compatible = "allwinner,sunxi-periph-clock";
			clock-output-names = "pll_periphahb0";
		};

		ahb1 {
			#clock-cells = <0x0>;
			compatible = "allwinner,sunxi-periph-clock";
			clock-output-names = "ahb1";
			linux,phandle = <0x95>;
			phandle = <0x95>;
		};

		apb1 {
			#clock-cells = <0x0>;
			compatible = "allwinner,sunxi-periph-clock";
			clock-output-names = "apb1";
		};

		apb2 {
			#clock-cells = <0x0>;
			compatible = "allwinner,sunxi-periph-clock";
			clock-output-names = "apb2";
			linux,phandle = <0x7e>;
			phandle = <0x7e>;
		};

		ahb2 {
			#clock-cells = <0x0>;
			compatible = "allwinner,sunxi-periph-clock";
			clock-output-names = "ahb2";
		};

		ths {
			#clock-cells = <0x0>;
			compatible = "allwinner,sunxi-periph-clock";
			clock-output-names = "ths";
			linux,phandle = <0x84>;
			phandle = <0x84>;
		};
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

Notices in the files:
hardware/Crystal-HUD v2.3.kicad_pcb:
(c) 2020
